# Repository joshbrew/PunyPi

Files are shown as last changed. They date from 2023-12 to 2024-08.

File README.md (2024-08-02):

# PunyPi (tbd)

rn_image_picker_lib_temp_c4f592c4-a881-4eb2-ad05-ee595f95a4bf

This is a standalone chiplet design that mounts the [TI AM625](https://www.ti.com/product/AM625) CortexA53 (up to 4 cores) and up to 8Gb DDR4 RAM. This chiplet allows you to create expansion boards in any size and shape you desire, and it's fully open source! This variant of the A53 runs at a higher clock than the RPi Zero 2 and we included the RAM so it is fully capable of more intensive compute tasks. 

This doesn't break out *every* feature of the AM625 but it does condense a fair amount to 30mm x 30mm on a 10 layer board. It works with standard throughole vias to help reduce PCB assembly costs. The Cortex A53 is getting older but is still one of the most popular industrial automation chips in the world and gives you good middle of the road performance - about that of a Samsung Galaxy S8 (EU edition) or Galaxy Watch 3. We're experimenting with microcomputers, servers, wearables, etc. and our best option was to design this base chiplet ourselves. 

Features:
- 1x DDR4 up to 8Gb
- 2x USB 2.0
- 1x LVDS screen (can bridge to HDMI) up to 1080p 60fps with up to Vulkan 1.2 support
- 1x JTAG
- 1x McASP Audio (4 channel)
- 2x RGMII Ethernet
- 1x MMC 5.1
- 1x SD 3.0
- UART, SPI, I2C, GPIO (and unused interfaces generally work as GPIO)
- Can be powered by 3.3V supply (up to 4A) which may change.

## Currently untested! Stay tuned!

Files were produced in Altium. You can import the PcbDoc to KiCAD there is an ASCII exported version for EAGLE importing. Chiplet footprints forthcoming for easily creating mounts for the chiplet.

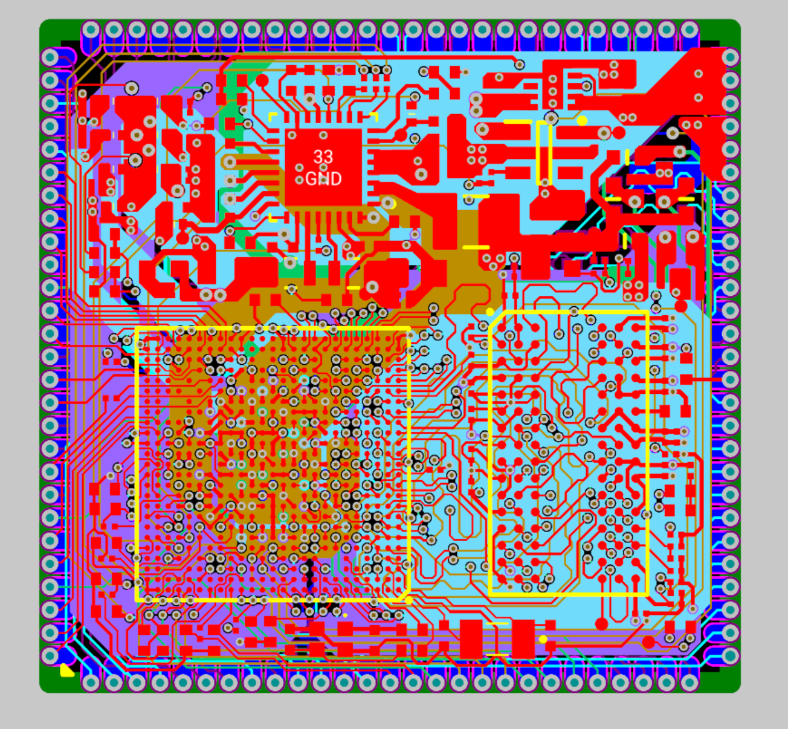
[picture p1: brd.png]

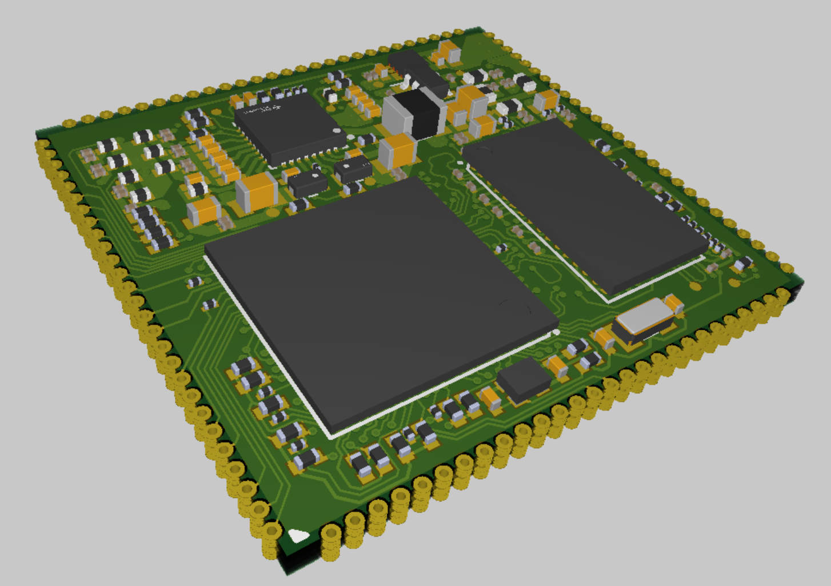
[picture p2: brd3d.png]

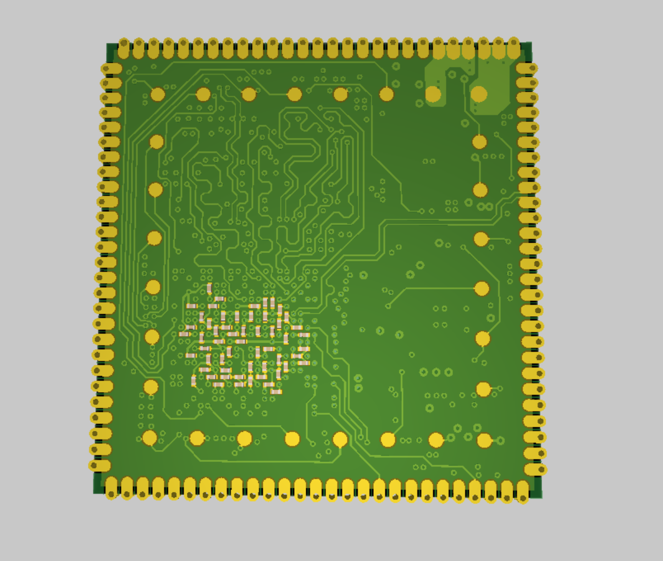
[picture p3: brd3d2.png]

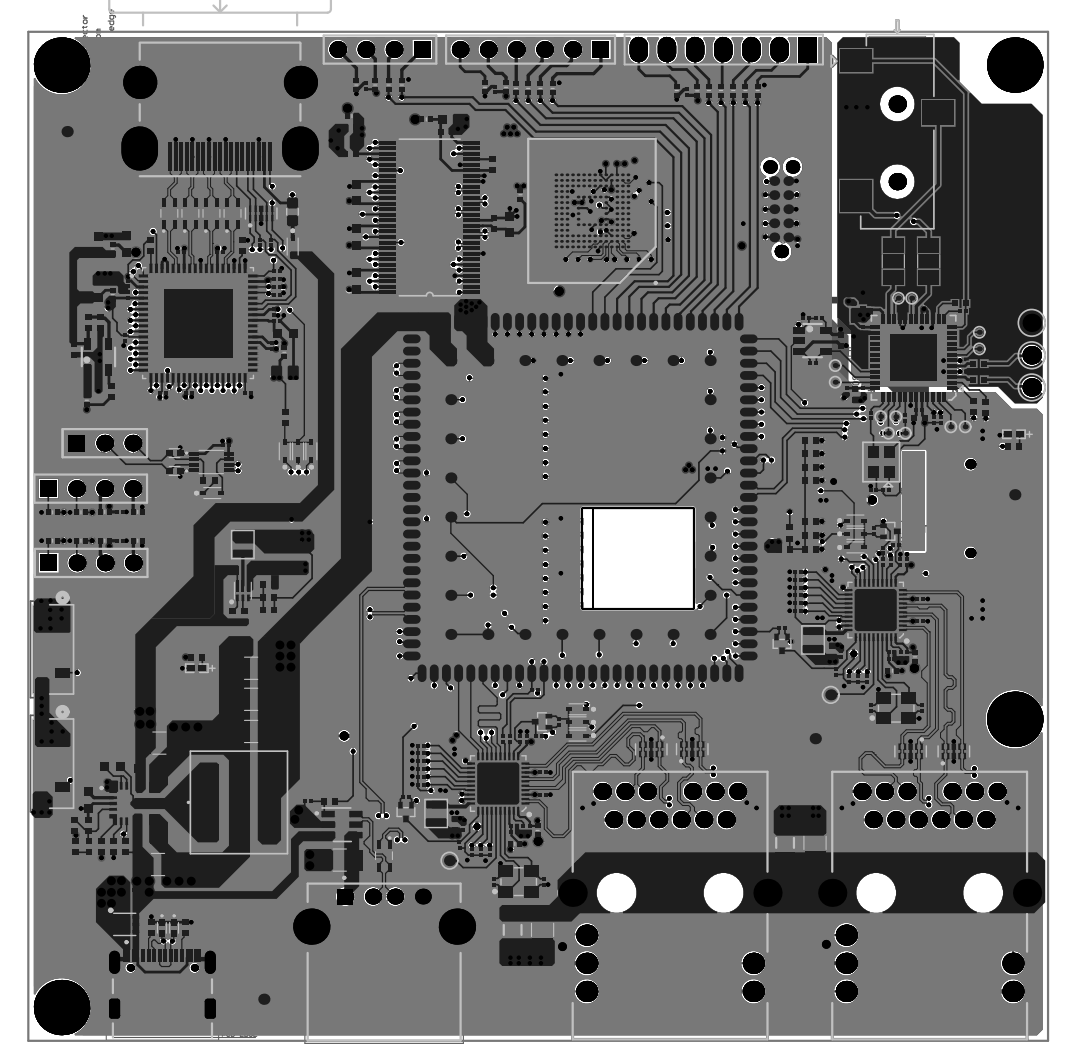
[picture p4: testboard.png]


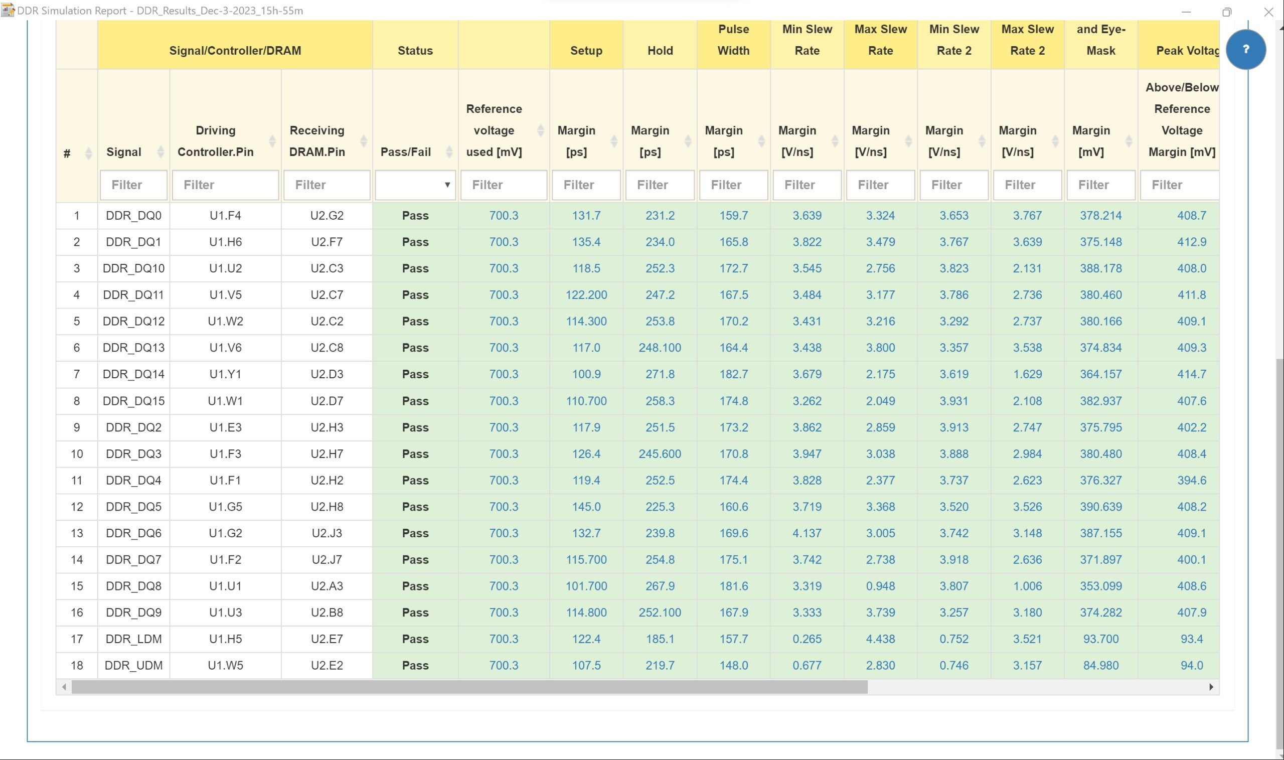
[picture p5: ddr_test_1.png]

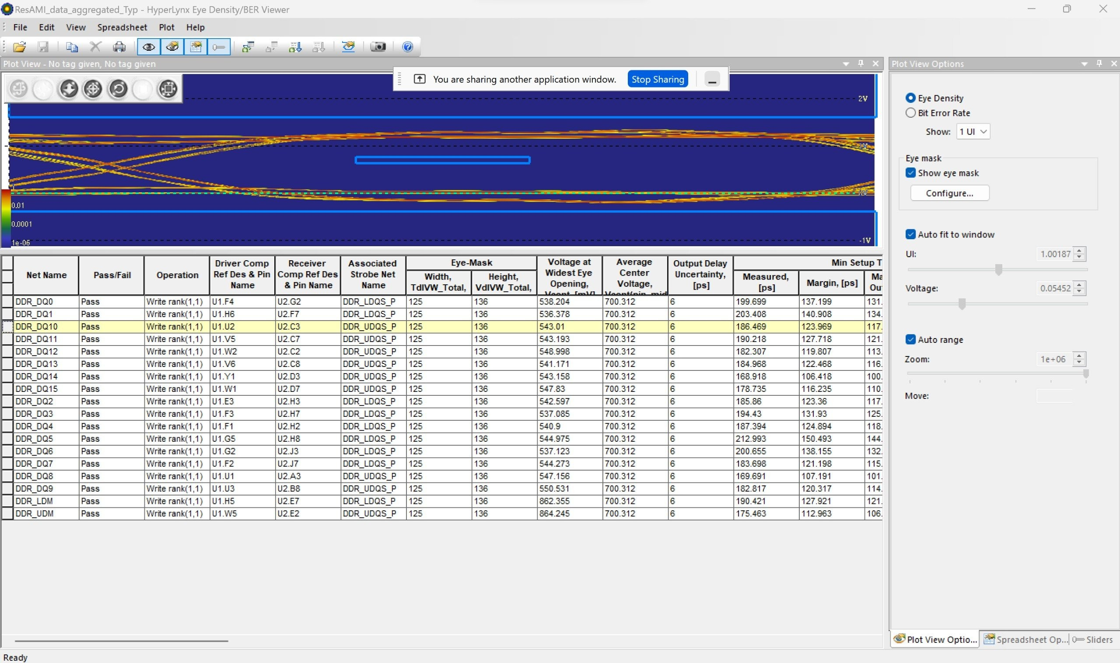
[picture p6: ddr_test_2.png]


We will release attachment/expansion boards for this that come prefabbed with ports etc, while the base board is just a chiplet. TI comes with standard toolings for flashing these devices, no licenses or anything required. We'll have all of this process documented for you on a full release. 

## License:

Drawings licensed under GNU GPL v3.0 (copyleft)

Please contribute to a future that's open source!

Credits:

- Drawing and validation by Nham (Paul) Phan
- Ideas/specifications by Josh Brewster and Yassine Santissi 

## Why

This is a FULLY open source alternative to RPi Zero 2. Just pay it forward and contribute to FOSS and open hardware. We're working on getting a bulk order to make these devices available at competitive prices with standard expansion boards built to house our modular ARM + RAM chiplet. We were inspired by Arducam's similar attempt with an older chipset that never saw the light of day.

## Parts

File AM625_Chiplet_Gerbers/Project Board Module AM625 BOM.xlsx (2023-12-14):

 |  | Bom List Som AM625
STT | Part Number | Manufacturer | Description | Designator | Footprint | Quantity
1 | C0603X5R1C103K030BA | TDK Corporation | CAP CER .01UF 16V 10% X5R 0201 | C1, C5, C6, C7, C8, C11, C12, C13, C14, C15, C16, C17, C18, C59, C62, C66, C69, C72, C75, C78, C81, C84, C135 | C0201 | 23
2 | C0603X5R1C104K030BC | TDK Corporation | CAP CER 0.1UF 16V 10% X5R 0201 | C2, C3, C10, C19, C20, C21, C58, C61, C65, C68, C71, C74, C77, C80, C83, C86, C91, C92, C93, C94, C95, C96, C97, C98, C99, C100, C101, C102, C103, C106, C107, C108, C109, C110, C111, C112, C113, C116, C117, C118, C119, C123, C124, C125, C126, C129, C130, C131, C132, C133, C134 | C0201 | 51
3 | C1005X5R1A225K | TDK Corporation | CAP CER 2.2UF 10V 10% X5R 0402 | C4, C29, C30, C32, C33, C35, C36, C37, C38 | C0402 | 9
4 | C1608X5R1A226M080AC | TDK Corporation | CAP CER 22UF 10V X5R 0603 | C9 | C0603 | 1
5 | CL21A476MQYNNNG | Samsung | 47 µF ±20% 6.3V Ceramic Capacitor X5R 0805 (2012 Metric) | C22, C28, C31 | C0805 | 3
6 | CL10A106MQ8NNNC | Samsung | 10 µF ±20% 6.3V Ceramic Capacitor X5R 0603 (1608 Metric) | C23, C40, C88, C120 | C0603 | 4
7 | C1005X5R1A475M | TDK Corporation | CAP CER 4.7UF 10V 20% X5R 0402 | C24, C25, C26, C27, C34 | C0402 | 5
8 | CL03A105KQ3CSNC | Samsung | CAP CER 1UF 6.3V X5R 0201 | C39, C42, C64, C67, C73, C79, C82, C87 | C0201 | 8
9 | C1005X5R1C105K | TDK Corporation | CAP CER 1.0UF 16V X5R 0402 | C41 | C0402 | 1
10 | C1005X5R1H104K | TDK Corporation | CAP CER .10UF 50V X5R 10% 0402 | C43 | C0402 | 1
11 | GJM1555C1H180JB01D | Murata | CAP CER 18PF 50V C0G/NP0 0402 | C44, C45 | C0402 | 2
12 | GJM1555C1H9R0DB01D | Murata | CAP CER 9PF 50V C0G/NP0 0402 | C46, C47 | C0402 | 2
13 | CL03A105KQ3CSNC | Samsung | CAP CER 1UF 6.3V X5R 0201 | C48, C49, C50, C51, C52, C53, C54, C55, C56, C90, C105, C115, C122, C128 | C0201 | 14
14 | C0603C0G1H2R2C030BA | TDK Corporation | CAP CER 2.2PF 50V C0G 0201 | C57 | C0201 | 1
15 | GRM035R60J475ME15D | Murata | CAP CER 4.7UF 6.3V X5R 0201 | C60, C63, C70, C76, C85, C89, C104, C114, C121, C127 | C0201 | 10
16 | BLM15PX121SN1D | Murata | FERRITE BEAD 120 OHM 0402 1LN | FL1, FL2, FL4, FL5, FL6, FL8, FL10, FL12, FL13 | NFZ15SG152SN10B | 9
17 | BLM18SG260TN1D | Murata | FERRITE BEAD 26 OHM 0603 1LN | FL3, FL7, FL9, FL11 | BLM18EG101TH1D | 4
18 | TPS6521904RHBR | Texas Instruments | INTEGRATED POWER MANAGEMENT | IC1 | 32-VQFN (5x5) | 1
19 | TPS22965DSGT | Texas Instruments | Integrated Circuit | IC2 | SON50P200X200X80-9N | 1
20 | TLV75518PDBVR | Texas Instruments | IC REG LINEAR 1.8V 500MA SOT23-5 | IC3 | SOT95P280X145-5N | 1
21 | DFE322520F-R47M=P2 | Murata | FIXED IND 0.47UH 8.5A | L1 | INDC3225X20N | 1
22 | TFM201208BLE-R47MTCF | TDK | 470 nH Shielded Thin Film Inductor 4 A 29mOhm Max 0805 (2012 Metric) | L2, L3 | FP-TFM201208BLE-R47MTCF_0805-MFG | 2
23 | RC0201FR-071KL | Yageo | RES 1K OHM 1/20W 1% 0201 SMD | R1, R2, R6, R7, R9, R12 | R0201 | 6
24 | RMCF0402FT39R2 | Stackpole Electronics | RES 39.2 OHM 1% 1/16W 0402 | R3, R4 | R0402 | 2
25 | RMCF0201FT240R | Stackpole Electronics Inc | RES 240 OHM 1/20W 1% 0201 | R5 | R0201 | 1
26 | RMCF0402FT240R | Stackpole Electronics Inc | RES TF 240 OHM 1% 0.0625W 0402 | R8 | R0402 | 1
27 | RC0201FR-0710KL | Yageo | RES 10K OHM 1/20W 1% 0201 SMD | R10, R11, R17, R32, R40, R41 | R0201 | 6
28 | RC0402FR-0722RL | Yageo | RES 22.0 OHM 1/16W 1% 0402 SMD | R13, R16 | R0402 | 2
29 | RC0402JR-070RL | Yageo | RES 0.0 OHM 1/16W 0402 SMD | R14, R26, R27, R28, R38, R39, R42 | R0402 | 7
30 | RC0402FR-0749R9L | Yageo | RES 49.9 OHM 1/16W 1% 0402 SMD | R15 | R0402 | 1
31 | RC0402FR-0710KL | Yageo | RES 10.0K OHM 1/16W 1% 0402 SMD | R18, R19, R20, R21, R29, R30, R53, R55, R57, R58 | R0402 | 10
32 | RC0201JR-070RL | Yageo | RES 0 OHM JUMPER 1/20W 0201 | R22, R23, R24, R25, R31 | R0201 | 5
33 | RC0402FR-072K2L | Yageo | RES 2.20K OHM 1/16W 1% 0402 SMD | R33, R34, R36, R37, R43, R44, R45, R46 | R0402 | 8
34 | RC0201FR-0733RL | Yageo | RES 33 OHM 1% 1/20W 0201 | R35, R47, R48, R51, R52 | R0201 | 5
35 | RC0201FR-0756K2L | Yageo | RES 56.2K OHM 1% 1/20W 0201 | R49 | R0201 | 1
36 | RC0201FR-079K76L | Yageo | RES 9.76K OHM 1% 1/20W 0201 | R50 | R0201 | 1
37 | RT0402BRD07499RL | Yageo | RES SMD 499 OHM 0.1% 1/16W 0402 | R54, R56 | R0402 | 2
38 | AM6254ATCGHAALW | Texas Instruments | ARM® Cortex®-A53 Microprocessor IC Sitara™ 4 Core, 64-Bit 1.4GHz 425-FCCSP (13x13) | U1 | BGA425C50P25X25_1300X1300X89 | 1
39 | MT40A1G16TB-062E:F | Micron Technology | SDRAM - DDR4 Memory IC 16Gbit Parallel 1.5 GHz 96-FBGA (7.5x13) | U2 | BGA96C80P9X16_750X1300X120 | 1
40 | XRCGB25M000F3M00R0 | Murata | CRYSTAL 25.0000MHZ 6PF SMD | Y1 | XRCGB25M000F3M00R0 | 1
41 | ECS-.327-9-34QCS-TR | ECS International | CRYSTAL 32.7680KHZ 9PF SMD | Y2 | ECS327934QSTR | 1

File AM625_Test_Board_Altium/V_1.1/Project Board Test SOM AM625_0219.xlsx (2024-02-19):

Manufacturer Part Number | Description | Manufacturer | Comment | Designator | Footprint | LibRef | Quantity
CGA3E1X5R1C105K080AC | Multilayer Ceramic Capacitor, 1 uF, 16 V, ± 10%, X5R, 0603 [1608 Metric] | TDK | 1uF | C101, C103, C105 | C0603 | CGA3E1X5R1C105K080AC | 3
C3216X5R1C106K160AA | Multilayer Ceramic Capacitor, 10 uF, 16 V, ± 10%, X5R, 1206 [3216 Metric] | TDK | 10uF | C102, C104 | C1206B/3216MM | C3216X5R1C106K160AA | 2
C3216X5R1C476M160AB, GRM31CR61A476ME15L | Multilayer Ceramic Capacitor, 47 uF, 16 V, ± 20%, X5R, 1206 [3216 Metric], Multilayer Ceramic Capacitor, 47 uF, 10 V, ± 20%, X5R, 1206 [3216 Metric] | TDK, Murata | 47uF | C106, C107, C108, C815, C816 | C1206B/3216MM | C3216X5R1C476M160AB, GRM31CR61A476ME15L | 5
C1608X7R1E104K080AA | Multilayer Ceramic Capacitor, 0.1 uF, 25 V, ± 10%, X7R, 0603 [1608 Metric] | TDK | 100nF | C109, C110, C302, C303, C304, C305, C307, C309 | C0603 | C1608X7R1E104K080AA | 8
CC0402FRNPO9BN360 | Capacitor Ceramic 36pF 50V C0G 1% 0402 Paper T/R | Yageo | 36pF | C111 | C0402 | CC0402FRNPO9BN360 | 1
C1608X5R1A106K080AC | Multilayer Ceramic Capacitor, 10 uF, 10 V, ± 10%, X5R, 0603 [1608 Metric] | TDK | 10uF | C112, C311, C318, C319, C322, C323, C701, C703 | C0603 | C1608X5R1A106K080AC | 8
C0402C121J3GAC7867 | Cap Ceramic 120pF 25V C0G 5% SMD 0402 125°C Paper T/R | KEMET | 120pF | C113 | C0402 | C0402C121J3GAC7867 | 1
CC0805MKX5R8BB226 | 22 µF ±20% 25V Ceramic Capacitor X5R 0805 (2012 Metric) | Yageo | 22uF | C114, C115, C213, C214 | C0805 | CC0805MKX5R8BB226 | 4
CC0402KRX5R6BB105 | Multilayer Ceramic Capacitor, 1 uF, 16 V, ± 20%, C0G (NP0), 0201 [0603 Metric] | Yageo | 1uF | C116, C117 | C0402 | CC0402KRX5R6BB105 | 2
CC0201KRX5R6BB104 | Multilayer Ceramic Capacitor, 0.1 uF, 16 V, ± 10%, X5R, 0201 [0603 Metric] | Yageo | 100nF | C201, C202, C203, C204, C206, C207, C208, C209, C210, C212, C216, C217, C312, C313, C314, C315, C316, C317, C320, C321, C324, C325, C326, C327, C502, C504, C506, C508, C510, C511, C512, C513, C515, C602, C604, C606, C608, C610, C611, C612, C613, C615, C702, C705, C901, C902, C903, C904, C905, C906, C907 | C0201 | CC0201KRX5R6BB104 | 51
CC0402MRX5R5BB475 | Multilayer Ceramic Capacitor, 4.7 uF, 6.3V, ± 10%, X5R, 0402 [1005 Metric] | Yageo | 4.7uF | C205, C211, C215, C301, C501, C505, C514, C601, C605, C614 | C0402 | CC0402MRX5R5BB475 | 10
C0402C103K4REC7411 | ESD SMD Comm X7R 0402 (1005Metric) ceramic capacitor 0.039Lx0.020W 1.00mmx0.50mm X7R ±10% 10000pF | KEMET | 10nF | C306, C308, C310 | C0402 | C0402C103K4REC7411 | 3
CC0201MRX5R5BB105 | 1 µF ±20% 6.3V Ceramic Capacitor X5R 0201 (0603 Metric) | Yageo | 1uF | C503, C507, C509, C603, C607, C609 | C0201 | CC0201MRX5R5BB105 | 6
C1005X5R1H104K050BB | Multilayer Ceramic Capacitor, 0.1 uF, 50 V, ± 10%, X5R, 0402 [1005 Metric] | TDK | 100nF | C516, C517, C518, C519, C520, C616, C617, C618, C619, C620 | C0402 | C1005X5R1H104K050BB | 10
CC0201JRNPO9BN220 | 0201 22 pF 50 V ±5 % Tolerance NP0 SMT Multilayer Ceramic Capacitor | Yageo | 22pF | C521, C522, C621, C622 | C0201 | CC0201JRNPO9BN220 | 4
C1206C102KDRACAUTO | Cap Ceramic 0.001uF 1000V X7R 10% Pad SMD 1206 125°C Low ESR Automotive Medical T/R | KEMET | 1nF | C523, C623 | C1206B/3216MM | C1206C102KDRACAUTO | 2
C3216X5R1A107M160AC | Multilayer Ceramic Capacitor, C Series, 100 - F, - 20%, X5R, 10 V, 1206 [3216 Metric] | TDK | 100uF | C704 | C1206B/3216MM | C3216X5R1A107M160AC | 1
GRM155R61A106ME11D | Multilayer Ceramic Capacitor, 10 uF, 10 V, ± 20%, X5R, 0402 [1005 Metric] | Murata | 10uF | C801, C803, C805, C806, C809 | C0402 | GRM155R61A106ME11D | 5
GRM033R61C104KE14D | Multilayer Ceramic Capacitor, 0.1 uF, 16 V, ± 10%, X5R, 0201 [0603 Metric] | Murata | 0.1uF | C802, C804, C807, C808, C810, C813, C814, C818 | C0201 | GRM033R61C104KE14D | 8
GRM155R71H104KE14D | Multilayer Ceramic Capacitor, 0.1 uF, 50 V, ± 10%, X7R, 0402 [1005 Metric] | Murata | 0.1uF | C811, C812, C819 | C0402 | GRM155R71H104KE14D | 3
GRM155R71A474KE01D | Multilayer Ceramic Capacitor, 0.47 uF, 10 V, ± 10%, X7R, 0402 [1005 Metric] | Murata | 0.47uF | C817 | C0402 | GRM155R71A474KE01D | 1
RB520S30T1G | Diode Schottky 30V 0.2A 2-Pin SOD-523 T/R - Product that comes on tape, but is not reeled | ON Semiconductor | RB520S30T1G | D201, D202, D203, D204, D205, D301, D303, D304, D305, D503, D504, D505, D603, D604, D605, D905 | sod_523 | RB520S30T1G | 16
TPD1E1B04DPYR | 1-pF, ±3.6-V, ±30-kV ESD protection diode with 6-A 8/20-uS surge & Low Clamping in 0402 package | Texas Instruments | TPD1E1B04DPYR | D206, D207, D208, D209, D210, D211, D212, D701, D702, D901, D902, D903, D904, D906, D907, D908, D909, D910, D911, D912, D913, D914, D915, D916, D917, D918 | DIO_TPD1E05U06DPYR | TPD1E1B04DPYR | 26
TPD4E05U06DQAR | Quad 0.5-pF, 5.5-V, ±12-kV ESD protection diode for USB, HDMI & High Speed Interfaces | Texas Instruments | TPD4E05U06DQAR | D302, D501, D502, D601, D602 | 10-USON | TPD4E05U06DQAR | 5
MF-FSMF010X-2 | PTC Resettable Fuse 0.1A(hold) 0.3A(trip) 15V 40A 0.5W 1s 0.9Ohm SMD Solder Pad 0603 T/R Automotive | Bourns | MF-FSMF010X-2 | F301 | f0603 | MF-FSMF010X-2 | 1
BLM15PD121SZ1D | Ferrite Beads Multi-Layer 120Ohm 25% 100MHz 1.3A 0.09Ohm DCR 0402 Automotive T/R | Murata | 120R | FB101, FB301, FB302, FB303, FB304, FB305, FB306, FB501, FB502, FB503, FB504, FB601, FB602, FB603, FB604, FB801, FB901, FB902, FB903, FB904, FB905, FB906, FB907, FB908, FB909, FB910, FB911, FB912, FB913, FB914, FB915, FB916, FB917, FB918, FB919, FB920, FB921, FB922, FB923, FB924, FB925 | FB0402 | BLM15PD121SZ1D | 41
GTFP08432B1HR | MICRO SD PUSH/PUSH SMALL 8C | Amphenol | GTFP08432B1HR | J201 | AMPHENOL_GTFP08432B1HR | CONN; MICRO SD PUSH/PUSH SMALL 8C, 5033981892 | 1
47151-0001 | CONN RCPT 19POS HDMI RT ANG SMD | Molex Connector Corporation | 47151-0001 | J301 | HDMI | 47151-0001 | 1
L829-1J1T-43 | CONN MAGJACK 1PORT SHLD 1000BT | Bel Fuse Inc | L829-1J1T-43 | J501, J601 | L829-1J1T-43 | L829-1J1T-43 | 2
USB4105-GF-A | Conn USB 2.0 Type C RCP 24 POS 0.3mm/0.5mm Solder RA SMD 24 Terminal 1 Port T/R | Global Connector Technology | TYPE_C 2.0 | J701 | GCT_USB4105-GF-A | USB4105-GF-A | 1
USB1130-15-A | Usb Conn, 2.0 Type A, R/a Rcpt, 4Pos, Th Rohs Compliant: Yes | Global Connector Technology | USB_A | J702 | GCT_USB1130-15-A_REVA | USB1130-15-A | 1
SJ-43514-SMT-TR | 3.5 mm, 4 Conductors, Right Angle, Surface Mount (SMT), Audio Jack Connector | CUI Devices | SJ-43514-SMT-TR | J801 | CON_AV4_SJ-43514-SMT_S_R_S_5-1 | SJ-43514-SMT-TR | 1
TS-104-T-AA | Header, 4 Pin Pitch 2.54mm |  | Header 4P | J901, J903, J905 | HDR1X4 | Header 4x1 | 3
TS-103-T-A |  |  | Header 1x3 | J904 | HDR1X3 | Header 1x3 | 1
74439358047 | Fixed Ind 4.7UH 9.5A 8.65 Mohm | Wurth Electronics | 4.7uH | L101 | IND_WE-XHMI_8080_WRE | 74439358047 | 1
DFE201610E-R47M=P2 | Inductor Power Shielded Wirewound 0.47uH 20% 1MHz Metal 3.6A 0.032Ohm DCR 0806 T/R | Murata | 0.47uH | L102 | l2016 | DFE201610E-R47M=P2 | 1
DLW21SN900HQ2L | Ind Common Mode Choke Wirewound 90Ohm 25% 100MHz 280mA 0805 Embossed T/R | Murata | DLW21SN900HQ2L | L301, L302, L303, L304, L701, L702 | IND_DLW21S_0805_MUR | DLW21SN900HQ2L | 6
DFE201610P-2R2M=P2 | Inductor Power Shielded Wirewound 2.2uH 20% 1MHz Metal 1.4A 0.168Ohm DCR 0806 T/R | Murata | 2.2uH | L501, L601 | l2016 | DFE201610P-2R2M=P2 | 2
BL-HGE37A-AV-TRB | Yellow Green 0402 1X.5X4MM | American Bright | Green | LED1001 | led0402_G | BL-HGE37A-AV-TRB | 1
SML-P12U2TT86R | LED Uni-Color Red 2-Pin Chip 0402(1006Metric) T/R | Rohm | Red | LED1002 | led0402_R | SML-P12U2TT86R | 1
TS-107-T-A | Header, 7-Pin, 2.54mm |  | Header 7 | P901 | HDR1X7 | Header 7x1 | 1
TS-106-T-A | Header, 6-Pin |  | Header 6 | P902 | HDR1X6 | Header 6x1 | 1
DMG1012T-7 | Transistor MOSFET NTR4003NT1G, SOT23, ON Semi | Diodes | DMG1012T-7 | Q501, Q502, Q601, Q602 | sot_523 | DMG1012T-7 | 4
RC0402FR-07100KL, AC0402FR-07100KL | SMD Chip Resistor, 100 kOhm, ± 1%, 63 mW, 0402 [1005 Metric], Thick Film, General Purpose | Yageo | 100K | R101, R103, R104, R110, R113 | R0402 | RC0402FR-07100KL, AC0402FR-07100KL | 5
RC0402FR-071KL | SMD Chip Resistor, 1 kOhm, ± 1%, 63 mW, 0402 [1005 Metric], Thick Film, General Purpose | Yageo | 1K | R102, R507, R508, R607, R608, R703 | R0402 | RC0402FR-071KL | 6
RC0402FR-0732K4L | SMD Chip Resistor, 32.4 kOhm, ± 1%, 63 mW, 0402 [1005 Metric], Thick Film, General Purpose | Yageo | 32.4K | R105 | R0402 | RC0402FR-0732K4L | 1
RC0402FR-0743K2L | SMD Chip Resistor, 43.2 kOhm, ± 1%, 63 mW, 0402 [1005 Metric], Thick Film, General Purpose | Yageo | 43.2K | R106 | R0402 | RC0402FR-0743K2L | 1
RC0402FR-0710KL | RES 10.0K OHM 1/16W 1% 0402 SMD | Yageo | 10K | R107, R108, R111, R210, R213, R214, R217, R218, R219, R220, R222, R223, R315, R901, R902, R903, R904, R905, R906, R907 | R0402 | RC0402FR-0710KL | 20
RC0402FR-07200KL | SMD Chip Resistor, 200 kOhm, ± 1%, 63 mW, 0402 [1005 Metric], Thick Film, General Purpose | Yageo | 200K | R109 | R0402 | RC0402FR-07200KL | 1
RC0402FR-07118KL | SMD Chip Resistor, 118 kOhm, ± 1%, 63 mW, 0402 [1005 Metric], Thick Film, General Purpose | Yageo | 118K | R112 | R0402 | RC0402FR-07118KL | 1
RC0402FR-0749K9L | SMD Chip Resistor, 49.9 kOhm, ± 1%, 63 mW, 0402 [1005 Metric], Thick Film, General Purpose | Yageo | 49.9K | R201, R202, R203, R204, R205, R206, R207, R208, R209, R212 | R0402 | RC0402FR-0749K9L | 10
RC0402JR-070RL | Zero Ohm Resistor, Jumper, 0402 [1005 Metric], Thick Film, 63 mW, 1 A, Surface Mount | Yageo | 0R | R211, R215, R216, R805, R806 | R0402 | RC0402JR-070RL | 5
RC0402FR-0710KL | RES 10.0K OHM 1/16W 1% 0402 SMD | Yageo | NC | R221 | R0402 | RC0402FR-0710KL | 1
RC0402FR-07100RL | SMD Chip Resistor, 100 Ohm, ± 1%, 63 mW, 0402 [1005 Metric], Thick Film, General Purpose | Yageo | 100R | R301, R304, R305, R306, R307 | R0402 | RC0402FR-07100RL | 5
RC0402JR-072K4L | Res Thick Film 0402 2.4K Ohm 5% 1/16W ±100ppm/°C Molded SMD Paper T/R | Yageo | 2.4K | R302, R303 | R0402 | RC0402JR-072K4L | 2
RC0201FR-072K2L | SMD Chip Resistor, 2.2 kOhm, ± 1%, 50 mW, 0201 [0603 Metric], Thick Film, General Purpose | Yageo | 2.2K | R308, R309, R502, R602, R803 | R0201 | RC0201FR-072K2L | 5
RC0402FR-074K7L | SMD Chip Resistor, 4.7 kOhm, ± 1%, 63 mW, 0402 [1005 Metric], Thick Film, General Purpose | Yageo | 4.7K | R310 | R0402 | RC0402FR-074K7L | 1
RC0201JR-0710KL, RC0201FR-0710KL | Res Thick Film 0201 10K Ohm 5% 1/20W ±200ppm/°C Molded SMD SMD Paper T/R, SMD Chip Resistor, 10 kOhm, ± 1%, 50 mW, 0201 [0603 Metric], Thick Film, General Purpose | Yageo | 10K | R311, R312, R520, R521, R524, R525, R620, R621, R624, R625, R807, R809, R810, R811, R814 | R0201 | RC0201JR-0710KL, RC0201FR-0710KL | 15
RC0402FR-074K3L | SMD Chip Resistor, 4.3 kOhm, ± 1%, 63 mW, 0402 [1005 Metric], Thick Film, General Purpose | Yageo | 4.3K | R313 | R0402 | RC0402FR-074K3L | 1
RC0201JR-070RL | Zero Ohm Resistor, Jumper, 0201 [0603 Metric], Thick Film, 50 mW, 500 mA, Surface Mount | Yageo | 0R | R314, R503, R504, R603, R604, R801, R802, R804, R808 | R0201 | RC0201JR-070RL | 9
RC0201FR-071K1L | SMD Chip Resistor, 1.1 kOhm, ± 1%, 50 mW, 0201 [0603 Metric], Thick Film, General Purpose | Yageo | 1.1K | R401, R402, R403, R404, R405, R406, R407, R408, R409, R410, R411, R412, R413, R414, R415, R416 | R0201 | RC0201FR-071K1L | 16
RC0201FR-07100KL | SMD Chip Resistor, 100 kOhm, ± 1%, 50 mW, 0201 [0603 Metric], Thick Film, General Purpose | Yageo | 100K | R417, R418, R419, R420, R421, R422, R423, R424, R425, R426, R427, R428, R429, R430, R431, R432 | R0201 | RC0201FR-07100KL | 16
RC0402JR-070RL | Zero Ohm Resistor, Jumper, 0402 [1005 Metric], Thick Film, 63 mW, 1 A, Surface Mount | Yageo | DNP | R501, R506, R601, R606 | R0402 | RC0402JR-070RL | 4
RC0201FR-072K49L | SMD Chip Resistor, 2.49 kOhm, ± 1%, 50 mW, 0201 [0603 Metric], Thick Film, General Purpose | Yageo | 2.49K | R505, R605 | R0201 | RC0201FR-072K49L | 2
RC1206FR-071ML | SMD Chip Resistor, 1 MOhm, ± 1%, 250 mW, 1206 [3216 Metric], Thick Film, General Purpose | Yageo | 1M | R509, R609 | R1206B/3216MM | RC1206FR-071ML | 2
RC0201JR-074K7L | SMD Chip Resistor, 4.7 kOhm, ± 5%, 50 mW, 0201 [0603 Metric], Thick Film, General Purpose | Yageo | 4.7K | R510, R512, R515, R516, R518, R522, R526, R528, R531, R610, R612, R615, R616, R618, R622, R626, R628, R631 | R0201 | RC0201JR-074K7L | 18
RC0201JR-074K7L | SMD Chip Resistor, 4.7 kOhm, ± 5%, 50 mW, 0201 [0603 Metric], Thick Film, General Purpose | Yageo | DNP | R511, R513, R514, R517, R519, R523, R527, R529, R530, R611, R613, R614, R617, R619, R623, R627, R629, R630 | R0201 | RC0201JR-074K7L | 18
AC0402FR-075K1L | SMD Chip Resistor, 5.1 kOhm, ± 1%, 63 mW, 0402 [1005 Metric], Thick Film, General Purpose | Yageo | 5.1K | R701, R702 | R0402 | AC0402FR-075K1L | 2
RC0201JR-0710KL | Res Thick Film 0201 10K Ohm 5% 1/20W ±200ppm/°C Molded SMD SMD Paper T/R | Yageo | DNI | R812, R813, R815 | R0201 | RC0201JR-0710KL | 3
RC0402FR-072K2L | SMD Chip Resistor, 2.2 kOhm, ± 1%, 63 mW, 0402 [1005 Metric], Thick Film, General Purpose | Yageo | 2.2K | R1001, R1002 | R0402 | RC0402FR-072K2L | 2
416131160808 | Slide Dip Switch, 8 Switches, 8PST, Latched, 0.025A, 24VDC, Solder Terminal, Surface Mount-straight | Wurth Electronics | 416131160808 | SW401, SW402 | SW_416131160808 | 416131160808 | 2
TL3330AF260QG | Switch Tactile N.O. SPST Rectangular Button Gull Wing 0.05A 12VDC 2.55N SMD | E-Switch | TL3330AF260QG | SW1001, SW1002 | SW_TL3330_EWI | TL3330AF260QG | 2
LMQ61460AASRJRR | Industrial 3-V to 36-V, 6-A, low-noise synchronous step-down converter 14-VQFN-HR -40 to 150 | Texas Instruments | LMQ61460AASRJRR | U101 | 14-VFQFN | LMQ61460AASRJRR | 1
TLV62595DMQR | 2.5-V to 5.5-V input, 4-A step-down converter with 1% output accuracy in 1.5-mm x 1.5-mm QFN package 6-VSON-HR -40 to... | Texas Instruments | TLV62595DMQR | U102 | VSON6_0D5_1D5X1D5X1MM | TLV62595DMQR | 1
TLV75801PDBVR | Adjustable 500-mA low-dropout (LDO) regulator 5-SOT-23 -40 to 125 | Texas Instruments | TLV75801PDBVR | U103 | SOT23-5 | TLV75801PDBVR | 1
KLMBG2JETD-B041 | eMMC 5.1 BGA-153 eMMC ROHS |  | KLMBG2JETD-B041 | U201 | BGA153C50P14X14_1150X1300X80 | KLMAG1JETD-B041 | 1
TPS22918DBVR | IC SINGLE CHANNEL LOAD SWITCH | Texas Instruments | TPS22918DBVR | U202 | SOT23-6 | TPS22918DBVR | 1
SN75LVDS82DGGR | 0/5 Receiver LVDS 56-TSSOP | Texas Instruments | SN75LVDS82DGGR | U301 | SOP50P810X120-56N | SN75LVDS82DGGR | 1
SII9022ACNU | 24-Bit RGB Input HDMI 1.4a Transmitter, 1080p@60Hz, no HDCP, 72-pin QFN | Lattice Semiconductor | SII9022ACNU | U302 | QFN50P1000X1000X90-73N | SII9022ACNU | 1
RTL8211F-VD-CG | IC, Interface, Ethernet, RTL8211F-VD-CG, QFN-40(5*5) | Realtek | RTL8211 | U501, U601 | qfn40_0D4_5x5mm | RTL8211 | 2
TVS0500DRVR | Diode TVS Single Uni-Dir 5V 400W 6-Pin WSON EP T/R | Texas Instruments | TVS0500DRVR | U701 | wson6_0d65_2x2x0_8mm | TVS0500DRVR | 1
TPD3S014DBVR | Current-limit switch and D+/D– ESD protection for USB Host ports 6-SOT-23 -40 to 85 | Texas Instruments | TPD3S014DBVR | U702 | SOT23-6 | TPD3S014DBVR | 1
TLV320AIC3106IRGZT | Very-Low-Power Stereo Audio CODEC With PowerTune Technology 32-VQFN -40 to 85 | Texas Instruments | TLV320AIC3106IRGZT | U801 | VQFN48_19-68_285X285 | TLV320AIC3204IRHBR | 1
KC2520Z12.2880C1KX00 | 12.288 MHz XO (Standard) CMOS Oscillator 1.71V ~ 3.63V Standby (Power Down) 4-SMD, No Lead | Kyocera AVX | 12.288MHz | U802 | OSC4_KC2520B_100X80_SMD_0-8 | XTAL OSC XO 12.2880MHZ CMOS SMD | 1
SN74LVC1G08DBVRE4 | Single 2-input, 1.65-V to 5.5-V AND gate 5-SOT-23 -40 to 125 | Texas Instruments | SN74LVC1G08DBVRE4 | U803 | SOT23-5 | SN74LVC1G08DBVRE4 | 1
SN74LVC2G241DCUR | Buffer, Non-Inverting 2 Element 1 Bit per Element Push-Pull Output US8 | Texas Instruments | SN74LVC2G241DCUR | U901 | DCU8-M | SN74LVC2G241DCUR | 1
LFXTAL055299 | Crystal, 25MHZ, 18PF, SMD | IQD | 25MHz | Y501, Y601 | x4-smd-3_2x2_5x1_0mm | LFXTAL055299 | 2
TC2050-IDC | PLUG-OF-NAILS 10-PIN W/ LEGS 8" | Tag-Connect LLC | TC2050-IDC | J902 | Header 2x5 |  | 1

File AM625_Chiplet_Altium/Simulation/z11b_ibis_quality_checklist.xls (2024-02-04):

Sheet: summary
This checklist will help validate the quality of an IBIS file.
Copy the component and Model tabs below so that this spreadsheet contains one tab
for each [Component] and [Model]. Fill in the tabs to determine the quality level for
each item, then complete the summary of IQ levels below to determine the overall
IQ level. For more information check the IBIS Quality Specification
Vendor | Micron Technology, Inc.
IBIS File | z11b.ibs
IBIS File | z11b_it.ibs
Rev | 2.9.2
Date | 2023-02-27
Overall IBIS Quality | 3MSX
IBISCHK Parser Information
Version | 6.1.2
Errors | 0
Warnings | 0
Caution | 0
Notes | Yes
Summary of IBIS Check
File Header
In column Pass/Fail below mark each item PASS, FAIL, NA or EXCEPTION.
The IQ level is the highest level number for which all checks PASS.
The IQ level is FAIL if no level completely passes.
See IBIS Quality Specification for complete descriptions of the checks.
IQ Spec Reference | IQ LEVEL | Description | PASS/FAIL | Comments
2.1 | LEVEL 1 | IBIS file passes IBISCHK | PASS
Components
Components | IQ LEVEL | Comments
Packaged - MT40A2G4SA, MT40A1G8SA, MT40A512M16LY | 3
Bare Die - MT40A2G4Z11B, MT40A1G8Z11B, MT40A512M16Z11B | 3
Models
Models | IQ LEVEL | Comments
I/O - DQ_34_*, DQ_40_*, DQ_48_*, DQS_34_*, DQS_40_*, DQS_48_* | 3MSX
Input - DQ_IN_, DQS_IN_, DM_*, INPUT, CLKIN, RESET, TEN | 3MS
Teminator - TDQS_*, NF_DQ , NF_INPUT | 3MS
Open_sink - ALERT | 3MS

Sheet: components(pkg)
COMPONENT(S): | MT40A2G4SA, MT40A1G8SA, MT40A512M16LY, MT40A2G4Z11B, MT40A1G8Z11B, MT40A512M16Z11B
IQ Level: | 3
Exception:
Correlation:
In column Pass/Fail below mark each item PASS, FAIL, NA or EXCEPTION.
The IQ level is the highest level number for which all checks PASS.
The IQ level is FAIL if no level completely passes.
See IBIS Quality Specification for complete descriptions of the checks.
IQ Spec Reference | IQ LEVEL | Description | PASS/FAIL | Comments
3.1.1 | LEVEL 2 | [Package] must have typ/min/max values | PASS
3.1.2 | LEVEL 2 | [Package] parasitics must be reasonable | PASS
3.2.1 | LEVEL 2 | [Pin] section complete | PASS
3.2.2 | LEVEL 3 | [Pin] RLC parasitics are present and reasonable | PASS
3.3.1 | LEVEL 2 | [Diff Pin] referenced pin models matched | PASS
3.3.2 | LEVEL 3 | [Diff Pin] Vdiff and Tdelay_* complete and reasonable | PASS
4.1 | LEVEL 2 | [Model Selector] entries have reasonable descriptions | PASS
4.2 | LEVEL 2 | Default [Model Selector] entries are consistent | PASS

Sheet: models(IO)
MODEL(S): | DQ_34_*, DQ_40_*, DQ_48_*, DQS_34_*, DQS_40_*, DQS_48_*
IQ Level: | 3
Exception: | 5.4.3 | V-t length is excessive due to inclusion of [Composite Current] I-t data.
Correlation: | MSX | Measuremant and Simulation Correlated
In column Pass/Fail below mark each item PASS, FAIL, NA or EXCEPTION.
The IQ level is the highest level number for which all checks PASS.
The IQ level is FAIL if no level completely passes.
See IBIS Quality Specification for complete descriptions of the checks.
IQ Spec Reference | IQ LEVEL | Description | PASS/FAIL | Comments
5.1.1 | LEVEL 2 | [Model] parameters have correct typ/min/max order | PASS
5.1.2 | LEVEL 2 | [Model] C_comp is reasonable | PASS
5.1.3 | LEVEL 2 | [Temperature Range] is reasonable | PASS
5.1.4 | LEVEL 2 | [Voltage Range] or [* Reference] is reasonable | PASS
5.2.1 | LEVEL 3 | [Model] Vinl and Vinh reasonable | PASS
5.2.2 | LEVEL 3 | [Model Spec] Vinl and Vinh reasonable | PASS
5.2.3 | LEVEL 3 | [Model Spec] Vinl+/- and Vinh+/- complete and reasonable | NA
5.2.5 | LEVEL 2 | [Model Spec] S_Overshoot subparameters complete and match data sheet | PASS
5.2.6 | LEVEL 2 | [Model Spec] S_Overshoot subparameters track typ/min/max | PASS
5.2.7 | LEVEL 2 | [Model Spec] D_Overshoot_* subparameters complete and match data sheet | PASS
5.2.8 | LEVEL 2 | [Model Spec] D_Overshoot_* subparameters track typ/min/max | PASS
5.2.9 | LEVEL 3 | [Receiver Thresholds] Vth present and matches data sheet, if needed | NA
5.2.10 | LEVEL 3 | [Receiver Thresholds] Vth_min and Vth_max present and match data sheet, if needed | NA
5.2.11 | LEVEL 3 | [Receiver Thresholds] Vinh_ac, Vinl_ac present and match data sheet, if needed | NA
5.2.12 | LEVEL 3 | [Receiver Thresholds] Vinh_dc, Vinl_dc present and match data sheet, if needed | NA
5.2.13 | LEVEL 3 | [Receiver Thresholds] Tslew_ac/Tdiffslew_ac present and match data sheet, if needed | NA
5.2.14 | LEVEL 3 | [Receiver Thresholds] Threshold_sensitivity and Ext_ref present and match data sheet, if needed | NA
5.3.1 | LEVEL 2 | I-V tables have correct typ/min/max order | PASS
5.3.2 | LEVEL 2 | [Pullup] voltage sweep range is correct | PASS
5.3.3 | LEVEL 2 | [Pulldown] voltage sweep range is correct | PASS
5.3.4 | LEVEL 2 | [POWER Clamp] voltage sweep range is correct | PASS
5.3.5 | LEVEL 2 | [GND Clamp] voltage sweep range is correct | PASS
5.3.6 | LEVEL 2 | I-V tables do not exhibit stair-stepping | PASS
5.3.7 | LEVEL 2 | Combined I-V tables are monotonic | PASS
5.3.8 | LEVEL 2 | [Pulldown] I-V tables pass through zero/zero | PASS
5.3.9 | LEVEL 2 | [Pullup] I-V tables pass through zero/zero | PASS
5.3.10 | LEVEL 2 | No leakage current in clamp I-V tables | PASS
5.3.11 | LEVEL 2 | I-V behavior not double-counted | PASS
5.3.12 | LEVEL 2 | On-die termination modeling documented | PASS
5.3.13 | LEVEL 2 | ECL models I-V tables swept from -Vcc to +2 * Vcc. | NA
5.3.14 | LEVEL 2 | Point distributions in I-V tables should be sufficient | PASS
5.4.1 | LEVEL 2 | Output and I/O buffers have sufficient V-T tables | PASS
5.4.2 | LEVEL 2 | V-T tables have reasonable point distribution | PASS
5.4.3 | LEVEL 3 | V-T table duration is not excessive | EXCEPTION | V-t length is long due to inclusion of [Composite Current] I-t data.
5.4.4 | LEVEL 2 | V-T table endpoints match fixture voltages | PASS
5.5.1 | LEVEL 2 | [Ramp] R_load present if value other than 50 ohms | PASS
5.5.2 | LEVEL 2 | [Ramp] typ/min/max order is correct | PASS
5.5.3 | LEVEL 2 | [Ramp] dV consistent with I-V table calculations | PASS
5.5.4 | LEVEL 2 | [Ramp] dt is consistent with 20%-80% crossing time | PASS
5.6.1 | LEVEL 3 | [Model Spec] Vmeas and Vref used if typ/min/max variation | PASS
5.6.2 | LEVEL 3 | Vref consistent for Open-drain, Open-source, and ECL Model_types | NA

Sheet: models(Input)
MODEL(S): | DQ_IN_, DQS_IN_, DM_*, INPUT, CLKIN, RESET, TEN
IQ Level: | 3
Exception:
Correlation: | MS | Measurement and Simulation Correlated
In column Pass/Fail below mark each item PASS, FAIL, NA or EXCEPTION.
The IQ level is the highest level number for which all checks PASS.
The IQ level is FAIL if no level completely passes.
See IBIS Quality Specification for complete descriptions of the checks.
IQ Spec Reference | IQ LEVEL | Description | PASS/FAIL | Comments
5.1.1 | LEVEL 2 | [Model] parameters have correct typ/min/max order | PASS
5.1.2 | LEVEL 2 | [Model] C_comp is reasonable | PASS
5.1.3 | LEVEL 2 | [Temperature Range] is reasonable | PASS
5.1.4 | LEVEL 2 | [Voltage Range] or [* Reference] is reasonable | PASS
5.2.1 | LEVEL 3 | [Model] Vinl and Vinh reasonable | PASS
5.2.2 | LEVEL 3 | [Model Spec] Vinl and Vinh reasonable | PASS
5.2.3 | LEVEL 3 | [Model Spec] Vinl+/- and Vinh+/- complete and reasonable | NA
5.2.5 | LEVEL 2 | [Model Spec] S_Overshoot subparameters complete and match data sheet | PASS
5.2.6 | LEVEL 2 | [Model Spec] S_Overshoot subparameters track typ/min/max | PASS
5.2.7 | LEVEL 2 | [Model Spec] D_Overshoot_* subparameters complete and match data sheet | PASS
5.2.8 | LEVEL 2 | [Model Spec] D_Overshoot_* subparameters track typ/min/max | PASS
5.2.9 | LEVEL 3 | [Receiver Thresholds] Vth present and matches data sheet, if needed | PASS
5.2.10 | LEVEL 3 | [Receiver Thresholds] Vth_min and Vth_max present and match data sheet, if needed | PASS
5.2.11 | LEVEL 3 | [Receiver Thresholds] Vinh_ac, Vinl_ac present and match data sheet, if needed | PASS
5.2.12 | LEVEL 3 | [Receiver Thresholds] Vinh_dc, Vinl_dc present and match data sheet, if needed | PASS
5.2.13 | LEVEL 3 | [Receiver Thresholds] Tslew_ac/Tdiffslew_ac present and match data sheet, if needed | PASS
5.2.14 | LEVEL 3 | [Receiver Thresholds] Threshold_sensitivity and Ext_ref present and match data sheet, if needed | PASS
5.3.1 | LEVEL 2 | I-V tables have correct typ/min/max order | PASS
5.3.2 | LEVEL 2 | [Pullup] voltage sweep range is correct | NA
5.3.3 | LEVEL 2 | [Pulldown] voltage sweep range is correct | NA
5.3.4 | LEVEL 2 | [POWER Clamp] voltage sweep range is correct | PASS
5.3.5 | LEVEL 2 | [GND Clamp] voltage sweep range is correct | PASS
5.3.6 | LEVEL 2 | I-V tables do not exhibit stair-stepping | PASS
5.3.7 | LEVEL 2 | Combined I-V tables are monotonic | PASS
5.3.8 | LEVEL 2 | [Pulldown] I-V tables pass through zero/zero | NA
5.3.9 | LEVEL 2 | [Pullup] I-V tables pass through zero/zero | NA
5.3.10 | LEVEL 2 | No leakage current in clamp I-V tables | PASS
5.3.11 | LEVEL 2 | I-V behavior not double-counted | PASS
5.3.12 | LEVEL 2 | On-die termination modeling documented | PASS
5.3.13 | LEVEL 2 | ECL models I-V tables swept from -Vcc to +2 * Vcc. | NA
5.3.14 | LEVEL 2 | Point distributions in I-V tables should be sufficient | PASS
5.4.1 | LEVEL 2 | Output and I/O buffers have sufficient V-T tables | NA
5.4.2 | LEVEL 2 | V-T tables have reasonable point distribution | NA
5.4.3 | LEVEL 3 | V-T table duration is not excessive | NA
5.4.4 | LEVEL 2 | V-T table endpoints match fixture voltages | NA
5.5.1 | LEVEL 2 | [Ramp] R_load present if value other than 50 ohms | NA
5.5.2 | LEVEL 2 | [Ramp] typ/min/max order is correct | NA
5.5.3 | LEVEL 2 | [Ramp] dV consistent with I-V table calculations | NA
5.5.4 | LEVEL 2 | [Ramp] dt is consistent with 20%-80% crossing time | NA
5.6.1 | LEVEL 3 | [Model Spec] Vmeas and Vref used if typ/min/max variation | NA
5.6.2 | LEVEL 3 | Vref consistent for Open-drain, Open-source, and ECL Model_types | NA

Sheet: models(Terminator)
MODEL(S): | TDQS_*, NF_DQ , NF_INPUT
IQ Level: | 3
Exception:
Correlation: | MS | Measurement and Simulation Correlated
In column Pass/Fail below mark each item PASS, FAIL, NA or EXCEPTION.
The IQ level is the highest level number for which all checks PASS.
The IQ level is FAIL if no level completely passes.
See IBIS Quality Specification for complete descriptions of the checks.
IQ Spec Reference | IQ LEVEL | Description | PASS/FAIL | Comments
5.1.1 | LEVEL 2 | [Model] parameters have correct typ/min/max order | PASS
5.1.2 | LEVEL 2 | [Model] C_comp is reasonable | PASS
5.1.3 | LEVEL 2 | [Temperature Range] is reasonable | PASS
5.1.4 | LEVEL 2 | [Voltage Range] or [* Reference] is reasonable | PASS
5.2.1 | LEVEL 3 | [Model] Vinl and Vinh reasonable | NA
5.2.2 | LEVEL 3 | [Model Spec] Vinl and Vinh reasonable | NA
5.2.3 | LEVEL 3 | [Model Spec] Vinl+/- and Vinh+/- complete and reasonable | NA
5.2.5 | LEVEL 2 | [Model Spec] S_Overshoot subparameters complete and match data sheet | NA
5.2.6 | LEVEL 2 | [Model Spec] S_Overshoot subparameters track typ/min/max | NA
5.2.7 | LEVEL 2 | [Model Spec] D_Overshoot_* subparameters complete and match data sheet | NA
5.2.8 | LEVEL 2 | [Model Spec] D_Overshoot_* subparameters track typ/min/max | NA
5.2.9 | LEVEL 3 | [Receiver Thresholds] Vth present and matches data sheet, if needed | NA
5.2.10 | LEVEL 3 | [Receiver Thresholds] Vth_min and Vth_max present and match data sheet, if needed | NA
5.2.11 | LEVEL 3 | [Receiver Thresholds] Vinh_ac, Vinl_ac present and match data sheet, if needed | NA
5.2.12 | LEVEL 3 | [Receiver Thresholds] Vinh_dc, Vinl_dc present and match data sheet, if needed | NA
5.2.13 | LEVEL 3 | [Receiver Thresholds] Tslew_ac/Tdiffslew_ac present and match data sheet, if needed | NA
5.2.14 | LEVEL 3 | [Receiver Thresholds] Threshold_sensitivity and Ext_ref present and match data sheet, if needed | NA
5.3.1 | LEVEL 2 | I-V tables have correct typ/min/max order | PASS
5.3.2 | LEVEL 2 | [Pullup] voltage sweep range is correct | NA
5.3.3 | LEVEL 2 | [Pulldown] voltage sweep range is correct | NA
5.3.4 | LEVEL 2 | [POWER Clamp] voltage sweep range is correct | PASS
5.3.5 | LEVEL 2 | [GND Clamp] voltage sweep range is correct | PASS
5.3.6 | LEVEL 2 | I-V tables do not exhibit stair-stepping | PASS
5.3.7 | LEVEL 2 | Combined I-V tables are monotonic | PASS
5.3.8 | LEVEL 2 | [Pulldown] I-V tables pass through zero/zero | NA
5.3.9 | LEVEL 2 | [Pullup] I-V tables pass through zero/zero | NA
5.3.10 | LEVEL 2 | No leakage current in clamp I-V tables | PASS
5.3.11 | LEVEL 2 | I-V behavior not double-counted | PASS
5.3.12 | LEVEL 2 | On-die termination modeling documented | PASS
5.3.13 | LEVEL 2 | ECL models I-V tables swept from -Vcc to +2 * Vcc. | NA
5.3.14 | LEVEL 2 | Point distributions in I-V tables should be sufficient | PASS
5.4.1 | LEVEL 2 | Output and I/O buffers have sufficient V-T tables | NA
5.4.2 | LEVEL 2 | V-T tables have reasonable point distribution | NA
5.4.3 | LEVEL 3 | V-T table duration is not excessive | NA
5.4.4 | LEVEL 2 | V-T table endpoints match fixture voltages | NA
5.5.1 | LEVEL 2 | [Ramp] R_load present if value other than 50 ohms | NA
5.5.2 | LEVEL 2 | [Ramp] typ/min/max order is correct | NA
5.5.3 | LEVEL 2 | [Ramp] dV consistent with I-V table calculations | NA
5.5.4 | LEVEL 2 | [Ramp] dt is consistent with 20%-80% crossing time | NA
5.6.1 | LEVEL 3 | [Model Spec] Vmeas and Vref used if typ/min/max variation | NA
5.6.2 | LEVEL 3 | Vref consistent for Open-drain, Open-source, and ECL Model_types | NA

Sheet: models(Open_drain)
MODEL(S): | ALERT
IQ Level: | 3
Exception:
Correlation: | MS | Measurement and Simulation Correlated
In column Pass/Fail below mark each item PASS, FAIL, NA or EXCEPTION.
The IQ level is the highest level number for which all checks PASS.
The IQ level is FAIL if no level completely passes.
See IBIS Quality Specification for complete descriptions of the checks.
IQ Spec Reference | IQ LEVEL | Description | PASS/FAIL | Comments
5.1.1 | LEVEL 2 | [Model] parameters have correct typ/min/max order | PASS
5.1.2 | LEVEL 2 | [Model] C_comp is reasonable | PASS
5.1.3 | LEVEL 2 | [Temperature Range] is reasonable | PASS
5.1.4 | LEVEL 2 | [Voltage Range] or [* Reference] is reasonable | PASS
5.2.1 | LEVEL 3 | [Model] Vinl and Vinh reasonable | NA
5.2.2 | LEVEL 3 | [Model Spec] Vinl and Vinh reasonable | NA
5.2.3 | LEVEL 3 | [Model Spec] Vinl+/- and Vinh+/- complete and reasonable | NA
5.2.5 | LEVEL 2 | [Model Spec] S_Overshoot subparameters complete and match data sheet | NA
5.2.6 | LEVEL 2 | [Model Spec] S_Overshoot subparameters track typ/min/max | NA
5.2.7 | LEVEL 2 | [Model Spec] D_Overshoot_* subparameters complete and match data sheet | NA
5.2.8 | LEVEL 2 | [Model Spec] D_Overshoot_* subparameters track typ/min/max | NA
5.2.9 | LEVEL 3 | [Receiver Thresholds] Vth present and matches data sheet, if needed | NA
5.2.10 | LEVEL 3 | [Receiver Thresholds] Vth_min and Vth_max present and match data sheet, if needed | NA
5.2.11 | LEVEL 3 | [Receiver Thresholds] Vinh_ac, Vinl_ac present and match data sheet, if needed | NA
5.2.12 | LEVEL 3 | [Receiver Thresholds] Vinh_dc, Vinl_dc present and match data sheet, if needed | NA
5.2.13 | LEVEL 3 | [Receiver Thresholds] Tslew_ac/Tdiffslew_ac present and match data sheet, if needed | NA
5.2.14 | LEVEL 3 | [Receiver Thresholds] Threshold_sensitivity and Ext_ref present and match data sheet, if needed | NA
5.3.1 | LEVEL 2 | I-V tables have correct typ/min/max order | PASS
5.3.2 | LEVEL 2 | [Pullup] voltage sweep range is correct | NA
5.3.3 | LEVEL 2 | [Pulldown] voltage sweep range is correct | PASS
5.3.4 | LEVEL 2 | [POWER Clamp] voltage sweep range is correct | PASS
5.3.5 | LEVEL 2 | [GND Clamp] voltage sweep range is correct | PASS
5.3.6 | LEVEL 2 | I-V tables do not exhibit stair-stepping | PASS
5.3.7 | LEVEL 2 | Combined I-V tables are monotonic | PASS
5.3.8 | LEVEL 2 | [Pulldown] I-V tables pass through zero/zero | PASS
5.3.9 | LEVEL 2 | [Pullup] I-V tables pass through zero/zero | NA
5.3.10 | LEVEL 2 | No leakage current in clamp I-V tables | PASS
5.3.11 | LEVEL 2 | I-V behavior not double-counted | PASS
5.3.12 | LEVEL 2 | On-die termination modeling documented | NA
5.3.13 | LEVEL 2 | ECL models I-V tables swept from -Vcc to +2 * Vcc. | NA
5.3.14 | LEVEL 2 | Point distributions in I-V tables should be sufficient | PASS
5.4.1 | LEVEL 2 | Output and I/O buffers have sufficient V-T tables | PASS
5.4.2 | LEVEL 2 | V-T tables have reasonable point distribution | PASS
5.4.3 | LEVEL 3 | V-T table duration is not excessive | PASS
5.4.4 | LEVEL 2 | V-T table endpoints match fixture voltages | PASS
5.5.1 | LEVEL 2 | [Ramp] R_load present if value other than 50 ohms | PASS
5.5.2 | LEVEL 2 | [Ramp] typ/min/max order is correct | PASS
5.5.3 | LEVEL 2 | [Ramp] dV consistent with I-V table calculations | PASS
5.5.4 | LEVEL 2 | [Ramp] dt is consistent with 20%-80% crossing time | PASS
5.6.1 | LEVEL 3 | [Model Spec] Vmeas and Vref used if typ/min/max variation | PASS
5.6.2 | LEVEL 3 | Vref consistent for Open-drain, Open-source, and ECL Model_types | PASS

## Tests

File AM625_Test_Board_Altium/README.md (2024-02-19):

1.1 has a different footprint for the Micro SD card, based on supply.

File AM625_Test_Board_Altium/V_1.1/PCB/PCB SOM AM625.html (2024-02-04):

Altium customize

# Board Information Report

Date: | | 12/25/2023
Time: | | 11:34:14 PM
Elapsed Time: | | 00:00:01
Filename: | | D:\HUST\02.OS\05.Project Board Test SOM AM625_2512\PCB\PCB SOM AM625.PcbDoc
Units: | | mmmils

## Contents

Contents

Board Specification

General

Routing

Routing Information

Layer Information

Layer Information

Drill Pairs

Copper Area

Copper Area

Board Holes

Non-Plated Hole Size

Plated Hole Size

Board Slots

Non-Plated Slot Size

Plated Slot Size

Board Square Holes

Non-Plated Square Hole Size

Plated Square Hole Size

Other

Top Layer Annular Ring Size

Mid Layer Annular Ring Size

Bottom Layer Annular Ring Size

Pad Solder Mask

Pad Paste Mask

Pad Pwr/Gnd Expansion

Pad Relief Conductor Width

Pad Relief Air Gap

Pad Relief Entries

Via Solder Mask

Track Width

Arc Line Width

Arc Radius

Arc Degrees

Text Height

Text Width

Net Track Width

Net Via Size

## Board Specification

General
Board Size | 152.4mm x 101.6mm
Components on board | 380

Back to top

## Routing

Routing Information
Routing completion | 12.13%
Connections | 1113
Connections routed | 135
Connections remaining | 978

Back to top

## Layer Information

Layer | Arcs | Pads | Vias | Tracks | Texts | Fills | Regions | ComponentBodies
Top Layer | 0 | 1260 | 0 | 0 | 0 | 0 | 12 | 0
Bottom Layer | 0 | 136 | 0 | 0 | 0 | 0 | 0 | 0
Mechanical 1 | 4 | 0 | 0 | 7 | 3 | 0 | 0 | 427
Top Assembly | 0 | 0 | 0 | 0 | 0 | 0 | 0 | 0
Top Value | 0 | 0 | 0 | 0 | 0 | 0 | 0 | 0
Mechanical 13 | 4 | 0 | 0 | 446 | 0 | 0 | 0 | 2
Mechanical 15 | 0 | 0 | 0 | 196 | 0 | 0 | 1 | 0
Mechanical 17 | 0 | 0 | 0 | 30 | 0 | 0 | 0 | 0
Mechanical 19 | 0 | 0 | 0 | 315 | 58 | 0 | 1 | 0
Bottom Value | 2 | 0 | 0 | 72 | 0 | 0 | 0 | 0
Mechanical 24 | 0 | 0 | 0 | 4 | 0 | 0 | 0 | 0
Mechanical 29 | 3 | 0 | 0 | 381 | 334 | 0 | 0 | 4
Bottom Assembly | 0 | 0 | 0 | 0 | 0 | 0 | 0 | 0
Multi-Layer | 0 | 263 | 0 | 4 | 0 | 0 | 4 | 0
Top Paste | 0 | 0 | 0 | 0 | 0 | 0 | 118 | 0
Top Overlay | 70 | 0 | 0 | 383 | 760 | 0 | 0 | 0
Top Solder | 0 | 0 | 0 | 0 | 0 | 0 | 106 | 0
Bottom Solder | 0 | 0 | 0 | 0 | 0 | 0 | 0 | 0
Bottom Overlay | 0 | 0 | 0 | 0 | 0 | 0 | 0 | 0
Bottom Paste | 0 | 0 | 0 | 0 | 0 | 0 | 0 | 0
Drill Guide | 0 | 0 | 0 | 0 | 0 | 0 | 0 | 0
Keep-Out Layer | 0 | 0 | 0 | 0 | 0 | 0 | 1 | 0
Drill Drawing | 0 | 0 | 0 | 0 | 0 | 0 | 0 | 0
Total | 83 | 1659 | 0 | 1838 | 1155 | 0 | 243 | 433

Back to top

Drill Pairs | Vias
Total | 0

Back to top

## Copper Area

Layer | Sq.In. | Sq.MM. | Percent of layer
Top Layer | 1.143 | 737.427 | 5%
Bottom Layer | 0.397 | 256.052 | 2%
Total | 1.54 | 993.479

Back to top

## Board Holes

Non-Plated Hole Size | Pads | Vias
0mm | 244 | 0
0.6096mm | 8 | 0
0.6604mm | 2 | 0
0.9mm | 2 | 0
1.1mm | 2 | 0
1.1999mm | 3 | 0
Total | 261 | 0

Back to top

Plated Hole Size | Pads | Vias
0mm | 1152 | 0
0.254mm | 36 | 0
0.4mm | 134 | 0
0.5mm | 1 | 0
0.9mm | 33 | 0
0.97mm | 4 | 0
1mm | 4 | 0
1.0668mm | 7 | 0
1.1mm | 4 | 0
1.3mm | 9 | 0
1.6002mm | 2 | 0
2mm | 2 | 0
3mm | 2 | 0
3.3mm | 2 | 0
Total | 1392 | 0

Back to top

## Board Slots

Non-Plated Slot Size / Length | Pads
Total | 0

Back to top

Plated Slot Size / Length | Pads
37.402mil / 92.52mil | 2
Total | 2

Back to top

## Board Square Holes

Non-Plated Square Hole Size | Pads
0.75mm | 2
1mm | 2
Total | 4

Back to top

Plated Square Hole Size | Pads
Total | 0

Back to top

## Other

Top Layer Annular Ring Size | Count
-3.3mm | 2
-0.39mm | 2
-0.14mm | 2
0mm | 16
0.0004mm | 1
0.254mm | 36
0.3mm | 1
0.4mm | 134
0.508mm | 4
0.55mm | 4
0.5842mm | 7
0.6mm | 21
0.605mm | 5
0.624mm | 12
0.8mm | 4
0.9mm | 4
0.9398mm | 2
1mm | 2
1mm | 2
1.966mm | 2
Total | 263

Back to top

Mid Layer Annular Ring Size | Count
-3.3mm | 2
-0.39mm | 2
-0.14mm | 2
0mm | 7
0.3mm | 1
0.4mm | 134
0.508mm | 4
0.55mm | 4
0.5842mm | 7
0.6mm | 21
0.605mm | 5
0.624mm | 12
0.8mm | 4
0.8636mm | 2
0.9mm | 4
0.9144mm | 8
0.9398mm | 2
1mm | 2
1mm | 2
1.27mm | 36
1.966mm | 2
Total | 263

Back to top

Bottom Layer Annular Ring Size | Count
-3.3mm | 2
-0.39mm | 2
-0.14mm | 2
0mm | 17
0.254mm | 36
0.3mm | 1
0.4mm | 134
0.508mm | 4
0.55mm | 4
0.5842mm | 7
0.6mm | 21
0.605mm | 5
0.624mm | 12
0.8mm | 4
0.9mm | 4
0.9398mm | 2
1mm | 2
1mm | 2
1.966mm | 2
Total | 263

Back to top

Pad Solder Mask | Count
-2.5654mm | 1
-0.4191mm | 48
-0.254mm | 36
0mm | 78
0.0254mm | 19
0.04mm | 202
0.05mm | 153
0.0508mm | 1
0.1016mm | 1121
Total | 1659

Back to top

Pad Paste Mask | Count
-4mm | 1
-2.5623mm | 1
-2mm | 1
-1.0541mm | 2
-1mm | 10
-0.9017mm | 2
-0.635mm | 1
-0.4123mm | 48
-0.3302mm | 2
-0.3048mm | 12
-0.254mm | 36
0mm | 1543
Total | 1659

Back to top

Pad Pwr/Gnd Expansion | Count
0.508mm | 1659
Total | 1659

Back to top

Pad Relief Conductor Width | Count
0.254mm | 1659
Total | 1659

Back to top

Pad Relief Air Gap | Count
0.254mm | 1659
Total | 1659

Back to top

Pad Relief Entries | Count
4 | 1659
Total | 1659

Back to top

Via Solder Mask | Count
Total | 0

Back to top

Track Width | Count
0mm | 234
0.0001mm | 3
0.0254mm | 114
0.05mm | 235
0.1mm | 755
0.127mm | 187
0.15mm | 20
0.1524mm | 32
0.1778mm | 4
0.2mm | 231
0.2032mm | 7
0.254mm | 12
0.6096mm | 4
Total | 1838

Back to top

Arc Line Width | Count
0mm | 6
0.0254mm | 2
0.127mm | 2
0.15mm | 26
0.1524mm | 8
0.1999mm | 1
0.2mm | 14
0.254mm | 4
0.3mm | 2
0.4mm | 16
0.508mm | 2
Total | 83

Back to top

Arc Radius | Count
0.02mm | 13
0.075mm | 26
0.0762mm | 8
0.1mm | 12
0.127mm | 5
0.1632mm | 2
0.2mm | 1
0.2074mm | 2
0.3048mm | 2
0.326mm | 2
0.3409mm | 2
0.381mm | 2
0.4mm | 4
2.8086mm | 1
12.7mm | 1
Total | 83

Back to top

Arc Degrees | Count
21 | 2
90 | 6
180 | 2
360 | 73
Total | 83

Back to top

Text Height | Count
0.5mm | 3
0.6mm | 116
1mm | 232
1.2mm | 2
1.524mm | 762
3mm | 40
Total | 1155

Back to top

Text Width | Count
0.1mm | 119
0.23mm | 2
0.254mm | 1034
Total | 1155

Back to top

Net Track Width | Count
0.254mm | 325
Total | 325

Back to top

Net Via Size | Count
1.27mm | 325
Total | 325

Back to top

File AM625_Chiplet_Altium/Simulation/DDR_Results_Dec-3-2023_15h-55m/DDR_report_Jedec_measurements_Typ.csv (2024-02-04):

Net Name | Pass/Fail | Operation | Driver Comp Ref Des & Pin Name | Receiver Comp Ref Des & Pin Name | Rise Rail Overshoot, [mV] | Rise Rail Overshoot Limit, [mV] | Rise Rail Overshoot Margin, [mV] | Rise Rail Overshoot, [Pass/Fail] | Rise Rail Overshoot Trace Point, [ns] | Fall Rail Undershoot, [mV] | Fall Rail Undershoot Limit, [mV] | Fall Rail Undershoot Margin, [mV] | Fall Rail Undershoot, [Pass/Fail] | Fall Rail Undershoot Trace Point, [ns] | Rise Rail Overshoot Area, [V*ns] | Rise Rail Overshoot Area Limit, [V*ns] | Rise Rail Overshoot Area Margin, [V*ns] | Rise Rail Overshoot Area, [Pass/Fail] | Rise Rail Overshoot Area Trace Point, [ns] | Fall Rail Undershoot Area, [V*ns] | Fall Rail Undershoot Area Limit, [V*ns] | Fall Rail Undershoot Area Margin, [V*ns] | Fall Rail Undershoot Area, [Pass/Fail] | Fall Rail Undershoot Area Trace Point, [ns] | Rise Rail Overshoot Area (2), [V*ns] | Rise Rail Overshoot Area (2) Limit, [V*ns] | Rise Rail Overshoot Area (2) Margin, [V*ns] | Rise Rail Overshoot Area (2), [Pass/Fail] | Rise Rail Overshoot Area (2) Trace Point, [ns] | Fall Rail Undershoot Area (2), [V*ns] | Fall Rail Undershoot Area (2) Limit, [V*ns] | Fall Rail Undershoot Area (2) Margin, [V*ns] | Fall Rail Undershoot Area (2), [Pass/Fail] | Fall Rail Undershoot Area (2) Trace Point, [ns] | Monotonic, [Pass/Fail] | Monotonic Trace Point, [ns] | VIH/L(AC) Min Limit, [Pass/Fail] | VIH/L(AC) Min Limit, Trace Point, [ns] | VIH/L(DC) Monotonicity, [Pass/Fail] | VIH/L(DC) Monotonicity Trace Point, [ns] | Vref Threshold Multi Cross, [Pass/Fail] | Max Slew Time, [ps] | Max Slew Time, [Pass/Fail] | VIX Limit Low, mV | VIX Limit Hi, mV | VIX Margin, mV | VIX, [Pass/Fail] | VIX Trace Point, [ns] | VID(AC) Limit, mV | VID(AC) Margin, mV | VID(AC), [Pass/Fail] | VID(AC) Trace Point, [ns] | VID(DC) Limit, mV | VID(DC), [Pass/Fail] | VID(DC) Trace Point, [ns] | Vdd/2, mV | VSEL Limit, mV | VSEL Margin, mV | VSEL, [Pass/Fail]
DDR_CLK_P | Pass | Write rank(1,1) | U1.L1&L2 | U2.K7&K8 | 0.0 | 300.0 | 300.0 | Pass | N/A | 0.0 | 300.0 | 300.0 | Pass | N/A | 0.0000 | 0.1125 | 0.1125 | Pass | N/A | 0.0000 | 0.1144 | 0.1144 | Pass | N/A | 0.0000 | 0.0038 | 0.0038 | Pass | N/A | N/A | N/A | N/A | N/A | N/A | Pass | N/A | N/A | N/A | N/A | N/A | Pass | 41.9 | Pass | 480.0 | 720.0 | 92.0 | Pass | 78.535 | 180.0 | 547.9 | Pass | 1.971 | 150.0 | Pass | N/A | 600.0 | 500.0 | 278.1 | Pass
DDR_LDQS_P | Pass | Write rank(1,1) | U1.E1&E2 | U2.G3&F3 | 27.1 | 400.0 | 372.9 | Pass | 2.729 | 0.0 | 400.0 | 400.0 | Pass | N/A | 0.0031 | 0.1050 | 0.1019 | Pass | 80.240 | 0.0000 | 0.1050 | 0.1050 | Pass | N/A | 0.0000 | 0.0150 | 0.0150 | Pass | N/A | 0.0000 | 0.0150 | 0.0150 | Pass | N/A | Pass | N/A | N/A | N/A | N/A | N/A | Pass | N/A | N/A | 671.8 | 1025.0 | 161.6 | Pass | 1.705 | N/A | N/A | N/A | N/A | N/A | N/A | N/A | N/A | N/A | N/A | N/A
DDR_UDQS_P | Pass | Write rank(1,1) | U1.V1&V2 | U2.B7&A7 | 25.6 | 400.0 | 374.4 | Pass | 2.108 | 0.0 | 400.0 | 400.0 | Pass | N/A | 0.0028 | 0.1050 | 0.1022 | Pass | 2.054 | 0.0000 | 0.1050 | 0.1050 | Pass | N/A | 0.0000 | 0.0150 | 0.0150 | Pass | N/A | 0.0000 | 0.0150 | 0.0150 | Pass | N/A | Pass | N/A | N/A | N/A | N/A | N/A | Pass | N/A | N/A | 683.0 | 1021.5 | 153.7 | Pass | 38.553 | N/A | N/A | N/A | N/A | N/A | N/A | N/A | N/A | N/A | N/A | N/A
DDR_A0 | Pass | Write rank(1,1) | U1.J1 | U2.P3 | 146.6 | 300.0 | 153.4 | Pass | 43.407 | 206.9 | 300.0 | 93.1 | Pass | 44.647 | 0.0347 | 0.2550 | 0.2203 | Pass | 58.309 | 0.0615 | 0.2644 | 0.2029 | Pass | 30.799 | 0.0000 | 0.0083 | 0.0083 | Pass | N/A | N/A | N/A | N/A | N/A | N/A | Pass | N/A | Pass | N/A | Pass | N/A | Pass | 27.9 | Pass | N/A | N/A | N/A | N/A | N/A | N/A | N/A | N/A | N/A | N/A | N/A | N/A | N/A | N/A | N/A | N/A
DDR_A1 | Pass | Write rank(1,1) | U1.J2 | U2.P7 | 205.0 | 300.0 | 95.0 | Pass | 68.419 | 269.4 | 300.0 | 30.6 | Pass | 40.903 | 0.0423 | 0.2550 | 0.2127 | Pass | 79.585 | 0.0677 | 0.2644 | 0.1967 | Pass | 67.069 | 0.0000 | 0.0083 | 0.0083 | Pass | N/A | N/A | N/A | N/A | N/A | N/A | Pass | N/A | Pass | N/A | Pass | N/A | Pass | 30.2 | Pass | N/A | N/A | N/A | N/A | N/A | N/A | N/A | N/A | N/A | N/A | N/A | N/A | N/A | N/A | N/A | N/A
DDR_A10 | Pass | Write rank(1,1) | U1.R5 | U2.M3 | 125.9 | 300.0 | 174.1 | Pass | 68.279 | 207.8 | 300.0 | 92.2 | Pass | 20.766 | 0.0262 | 0.2550 | 0.2288 | Pass | 68.269 | 0.0487 | 0.2644 | 0.2157 | Pass | 20.754 | 0.0000 | 0.0083 | 0.0083 | Pass | N/A | N/A | N/A | N/A | N/A | N/A | Pass | N/A | Pass | N/A | Pass | N/A | Pass | 30.2 | Pass | N/A | N/A | N/A | N/A | N/A | N/A | N/A | N/A | N/A | N/A | N/A | N/A | N/A | N/A | N/A | N/A
DDR_A11 | Pass | Write rank(1,1) | U1.P5 | U2.T2 | 141.4 | 300.0 | 158.6 | Pass | 62.051 | 218.5 | 300.0 | 81.5 | Pass | 7.036 | 0.0285 | 0.2550 | 0.2265 | Pass | 69.536 | 0.0507 | 0.2644 | 0.2137 | Pass | 78.270 | 0.0000 | 0.0083 | 0.0083 | Pass | N/A | N/A | N/A | N/A | N/A | N/A | Pass | N/A | Pass | N/A | Pass | N/A | Pass | 37.2 | Pass | N/A | N/A | N/A | N/A | N/A | N/A | N/A | N/A | N/A | N/A | N/A | N/A | N/A | N/A | N/A | N/A
DDR_A12 | Pass | Write rank(1,1) | U1.R6 | U2.M7 | 131.5 | 300.0 | 168.5 | Pass | 3.288 | 209.8 | 300.0 | 90.2 | Pass | 32.022 | 0.0269 | 0.2550 | 0.2281 | Pass | 3.268 | 0.0487 | 0.2644 | 0.2157 | Pass | 32.005 | 0.0000 | 0.0083 | 0.0083 | Pass | N/A | N/A | N/A | N/A | N/A | N/A | Pass | N/A | Pass | N/A | Pass | N/A | Pass | 32.6 | Pass | N/A | N/A | N/A | N/A | N/A | N/A | N/A | N/A | N/A | N/A | N/A | N/A | N/A | N/A | N/A | N/A
DDR_A13 | Pass | Write rank(1,1) | U1.R1 | U2.T8 | 162.3 | 300.0 | 137.7 | Pass | 78.445 | 214.4 | 300.0 | 85.6 | Pass | 9.681 | 0.0427 | 0.2550 | 0.2123 | Pass | 78.347 | 0.0706 | 0.2644 | 0.1938 | Pass | 9.585 | 0.0000 | 0.0083 | 0.0083 | Pass | N/A | N/A | N/A | N/A | N/A | N/A | Pass | N/A | Pass | N/A | Pass | N/A | Pass | 30.2 | Pass | N/A | N/A | N/A | N/A | N/A | N/A | N/A | N/A | N/A | N/A | N/A | N/A | N/A | N/A | N/A | N/A
DDR_A14_WEn | Pass | Write rank(1,1) | U1.N3 | U2.L2 | 127.1 | 300.0 | 172.9 | Pass | 24.623 | 199.6 | 300.0 | 100.4 | Pass | 45.864 | 0.0295 | 0.2550 | 0.2255 | Pass | 27.046 | 0.0532 | 0.2644 | 0.2112 | Pass | 62.031 | 0.0000 | 0.0083 | 0.0083 | Pass | N/A | N/A | N/A | N/A | N/A | N/A | Pass | N/A | Pass | N/A | Pass | N/A | Pass | 30.2 | Pass | N/A | N/A | N/A | N/A | N/A | N/A | N/A | N/A | N/A | N/A | N/A | N/A | N/A | N/A | N/A | N/A
DDR_A15_CAS | Pass | Write rank(1,1) | U1.M4 | U2.M8 | 151.4 | 300.0 | 148.6 | Pass | 4.560 | 217.4 | 300.0 | 82.6 | Pass | 63.300 | 0.0320 | 0.2550 | 0.2230 | Pass | 10.797 | 0.0538 | 0.2644 | 0.2106 | Pass | 27.032 | 0.0000 | 0.0083 | 0.0083 | Pass | N/A | N/A | N/A | N/A | N/A | N/A | Pass | N/A | Pass | N/A | Pass | N/A | Pass | 32.6 | Pass | N/A | N/A | N/A | N/A | N/A | N/A | N/A | N/A | N/A | N/A | N/A | N/A | N/A | N/A | N/A | N/A
DDR_A16_RAS | Pass | Write rank(1,1) | U1.M5 | U2.L8 | 155.5 | 300.0 | 144.5 | Pass | 54.561 | 224.1 | 300.0 | 75.9 | Pass | 39.549 | 0.0329 | 0.2550 | 0.2221 | Pass | 27.048 | 0.0566 | 0.2644 | 0.2078 | Pass | 25.780 | 0.0000 | 0.0083 | 0.0083 | Pass | N/A | N/A | N/A | N/A | N/A | N/A | Pass | N/A | Pass | N/A | Pass | N/A | Pass | 32.6 | Pass | N/A | N/A | N/A | N/A | N/A | N/A | N/A | N/A | N/A | N/A | N/A | N/A | N/A | N/A | N/A | N/A
DDR_A2 | Pass | Write rank(1,1) | U1.K3 | U2.R3 | 169.0 | 300.0 | 131.0 | Pass | 53.407 | 235.0 | 300.0 | 65.0 | Pass | 69.647 | 0.0392 | 0.2550 | 0.2158 | Pass | 53.326 | 0.0644 | 0.2644 | 0.2000 | Pass | 52.061 | 0.0000 | 0.0083 | 0.0083 | Pass | N/A | N/A | N/A | N/A | N/A | N/A | Pass | N/A | Pass | N/A | Pass | N/A | Pass | 30.2 | Pass | N/A | N/A | N/A | N/A | N/A | N/A | N/A | N/A | N/A | N/A | N/A | N/A | N/A | N/A | N/A | N/A
DDR_A3 | Pass | Write rank(1,1) | U1.L5 | U2.N7 | 146.3 | 300.0 | 153.7 | Pass | 48.298 | 218.4 | 300.0 | 81.6 | Pass | 62.039 | 0.0307 | 0.2550 | 0.2243 | Pass | 63.285 | 0.0535 | 0.2644 | 0.2109 | Pass | 42.020 | 0.0000 | 0.0083 | 0.0083 | Pass | N/A | N/A | N/A | N/A | N/A | N/A | Pass | N/A | Pass | N/A | Pass | N/A | Pass | 30.2 | Pass | N/A | N/A | N/A | N/A | N/A | N/A | N/A | N/A | N/A | N/A | N/A | N/A | N/A | N/A | N/A | N/A
DDR_A4 | Pass | Write rank(1,1) | U1.K4 | U2.N3 | 160.7 | 300.0 | 139.3 | Pass | 59.559 | 227.8 | 300.0 | 72.2 | Pass | 5.807 | 0.0349 | 0.2550 | 0.2201 | Pass | 59.550 | 0.0583 | 0.2644 | 0.2061 | Pass | 10.784 | 0.0000 | 0.0083 | 0.0083 | Pass | N/A | N/A | N/A | N/A | N/A | N/A | Pass | N/A | Pass | N/A | Pass | N/A | Pass | 30.2 | Pass | N/A | N/A | N/A | N/A | N/A | N/A | N/A | N/A | N/A | N/A | N/A | N/A | N/A | N/A | N/A | N/A
DDR_A5 | Pass | Write rank(1,1) | U1.K1 | U2.P8 | 165.1 | 300.0 | 134.9 | Pass | 27.215 | 216.6 | 300.0 | 83.4 | Pass | 40.955 | 0.0432 | 0.2550 | 0.2118 | Pass | 42.114 | 0.0706 | 0.2644 | 0.1938 | Pass | 3.353 | 0.0000 | 0.0083 | 0.0083 | Pass | N/A | N/A | N/A | N/A | N/A | N/A | Pass | N/A | Pass | N/A | Pass | N/A | Pass | 32.6 | Pass | N/A | N/A | N/A | N/A | N/A | N/A | N/A | N/A | N/A | N/A | N/A | N/A | N/A | N/A | N/A | N/A
DDR_A6 | Pass | Write rank(1,1) | U1.R2 | U2.P2 | 156.5 | 300.0 | 143.5 | Pass | 42.150 | 224.2 | 300.0 | 75.8 | Pass | 47.134 | 0.0354 | 0.2550 | 0.2196 | Pass | 4.574 | 0.0601 | 0.2644 | 0.2043 | Pass | 73.309 | 0.0000 | 0.0083 | 0.0083 | Pass | N/A | N/A | N/A | N/A | N/A | N/A | Pass | N/A | Pass | N/A | Pass | N/A | Pass | 27.9 | Pass | N/A | N/A | N/A | N/A | N/A | N/A | N/A | N/A | N/A | N/A | N/A | N/A | N/A | N/A | N/A | N/A
DDR_A7 | Pass | Write rank(1,1) | U1.P2 | U2.R8 | 179.9 | 300.0 | 120.1 | Pass | 22.190 | 235.7 | 300.0 | 64.3 | Pass | 35.929 | 0.0450 | 0.2550 | 0.2100 | Pass | 22.099 | 0.0710 | 0.2644 | 0.1934 | Pass | 42.090 | 0.0000 | 0.0083 | 0.0083 | Pass | N/A | N/A | N/A | N/A | N/A | N/A | Pass | N/A | Pass | N/A | Pass | N/A | Pass | 32.6 | Pass | N/A | N/A | N/A | N/A | N/A | N/A | N/A | N/A | N/A | N/A | N/A | N/A | N/A | N/A | N/A | N/A
DDR_A8 | Pass | Write rank(1,1) | U1.P1 | U2.R2 | 187.8 | 300.0 | 112.2 | Pass | 38.451 | 241.3 | 300.0 | 58.7 | Pass | 53.435 | 0.0489 | 0.2550 | 0.2061 | Pass | 48.360 | 0.0759 | 0.2644 | 0.1885 | Pass | 42.100 | 0.0000 | 0.0083 | 0.0083 | Pass | N/A | N/A | N/A | N/A | N/A | N/A | Pass | N/A | Pass | N/A | Pass | N/A | Pass | 30.2 | Pass | N/A | N/A | N/A | N/A | N/A | N/A | N/A | N/A | N/A | N/A | N/A | N/A | N/A | N/A | N/A | N/A
DDR_A9 | Pass | Write rank(1,1) | U1.P4 | U2.R7 | 153.1 | 300.0 | 146.9 | Pass | 15.805 | 219.0 | 300.0 | 81.0 | Pass | 73.298 | 0.0328 | 0.2550 | 0.2222 | Pass | 3.297 | 0.0549 | 0.2644 | 0.2095 | Pass | 62.031 | 0.0000 | 0.0083 | 0.0083 | Pass | N/A | N/A | N/A | N/A | N/A | N/A | Pass | N/A | Pass | N/A | Pass | N/A | Pass | 30.2 | Pass | N/A | N/A | N/A | N/A | N/A | N/A | N/A | N/A | N/A | N/A | N/A | N/A | N/A | N/A | N/A | N/A
DDR_ACTn | Pass | Write rank(1,1) | U1.N6 | U2.L3 | 111.6 | 300.0 | 188.4 | Pass | 44.487 | 182.3 | 300.0 | 117.7 | Pass | 41.969 | 0.0182 | 0.2550 | 0.2368 | Pass | 44.475 | 0.0365 | 0.2644 | 0.2279 | Pass | 61.952 | 0.0000 | 0.0083 | 0.0083 | Pass | N/A | N/A | N/A | N/A | N/A | N/A | Pass | N/A | Pass | N/A | Pass | N/A | Pass | 30.2 | Pass | N/A | N/A | N/A | N/A | N/A | N/A | N/A | N/A | N/A | N/A | N/A | N/A | N/A | N/A | N/A | N/A
DDR_BA0 | Pass | Write rank(1,1) | U1.M1 | U2.N2 | 137.7 | 300.0 | 162.3 | Pass | 47.209 | 193.9 | 300.0 | 106.1 | Pass | 7.194 | 0.0370 | 0.2550 | 0.2180 | Pass | 73.353 | 0.0637 | 0.2644 | 0.2007 | Pass | 27.091 | 0.0000 | 0.0083 | 0.0083 | Pass | N/A | N/A | N/A | N/A | N/A | N/A | Pass | N/A | Pass | N/A | Pass | N/A | Pass | 32.6 | Pass | N/A | N/A | N/A | N/A | N/A | N/A | N/A | N/A | N/A | N/A | N/A | N/A | N/A | N/A | N/A | N/A
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

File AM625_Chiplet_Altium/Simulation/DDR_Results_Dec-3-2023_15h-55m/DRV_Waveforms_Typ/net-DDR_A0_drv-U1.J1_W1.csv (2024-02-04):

.HEADER
..NAMES
Time | V U1.J1
.DATA
0.0e+00 | 0.0027
2.33e-11 | 0.0027
4.65e-11 | 0.0027
6.98e-11 | 0.0027
9.31e-11 | 0.0027
1.163e-10 | 0.0027
1.396e-10 | 0.0027
1.629e-10 | 0.0059
1.861e-10 | 0.0321
2.094e-10 | 0.1137
2.327e-10 | 0.2741
2.559e-10 | 0.4022
2.792e-10 | 0.5059
3.025e-10 | 0.5803
3.257e-10 | 0.6256
3.490e-10 | 0.6492
3.723e-10 | 0.6591
3.955e-10 | 0.6619
4.188e-10 | 0.6610
4.421e-10 | 0.6559
4.653e-10 | 0.6508
4.886e-10 | 0.6464
5.119e-10 | 0.6434
5.351e-10 | 0.6420
5.584e-10 | 0.6432
5.817e-10 | 0.6466
6.049e-10 | 0.6517
6.282e-10 | 0.6583
6.515e-10 | 0.6665
6.747e-10 | 0.6773
6.980e-10 | 0.6915
7.213e-10 | 0.7137
7.445e-10 | 0.7501
7.678e-10 | 0.8006
7.911e-10 | 0.8615
8.143e-10 | 0.9292
8.376e-10 | 0.9988
8.609e-10 | 1.0634
8.841e-10 | 1.1183
9.074e-10 | 1.1622
9.307e-10 | 1.1961
9.539e-10 | 1.2211
9.772e-10 | 1.2375
1.0005e-09 | 1.2464
1.0237e-09 | 1.2497
1.0470e-09 | 1.2492
1.0703e-09 | 1.2460
1.0935e-09 | 1.2414
1.1168e-09 | 1.2365
1.1401e-09 | 1.2326
1.1633e-09 | 1.2307
1.1866e-09 | 1.2314
1.2099e-09 | 1.2341
1.2332e-09 | 1.2360
1.2564e-09 | 1.2340
1.2797e-09 | 1.2268
1.3030e-09 | 1.2139
1.3262e-09 | 1.1964
1.3495e-09 | 1.1768
1.3728e-09 | 1.1591
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

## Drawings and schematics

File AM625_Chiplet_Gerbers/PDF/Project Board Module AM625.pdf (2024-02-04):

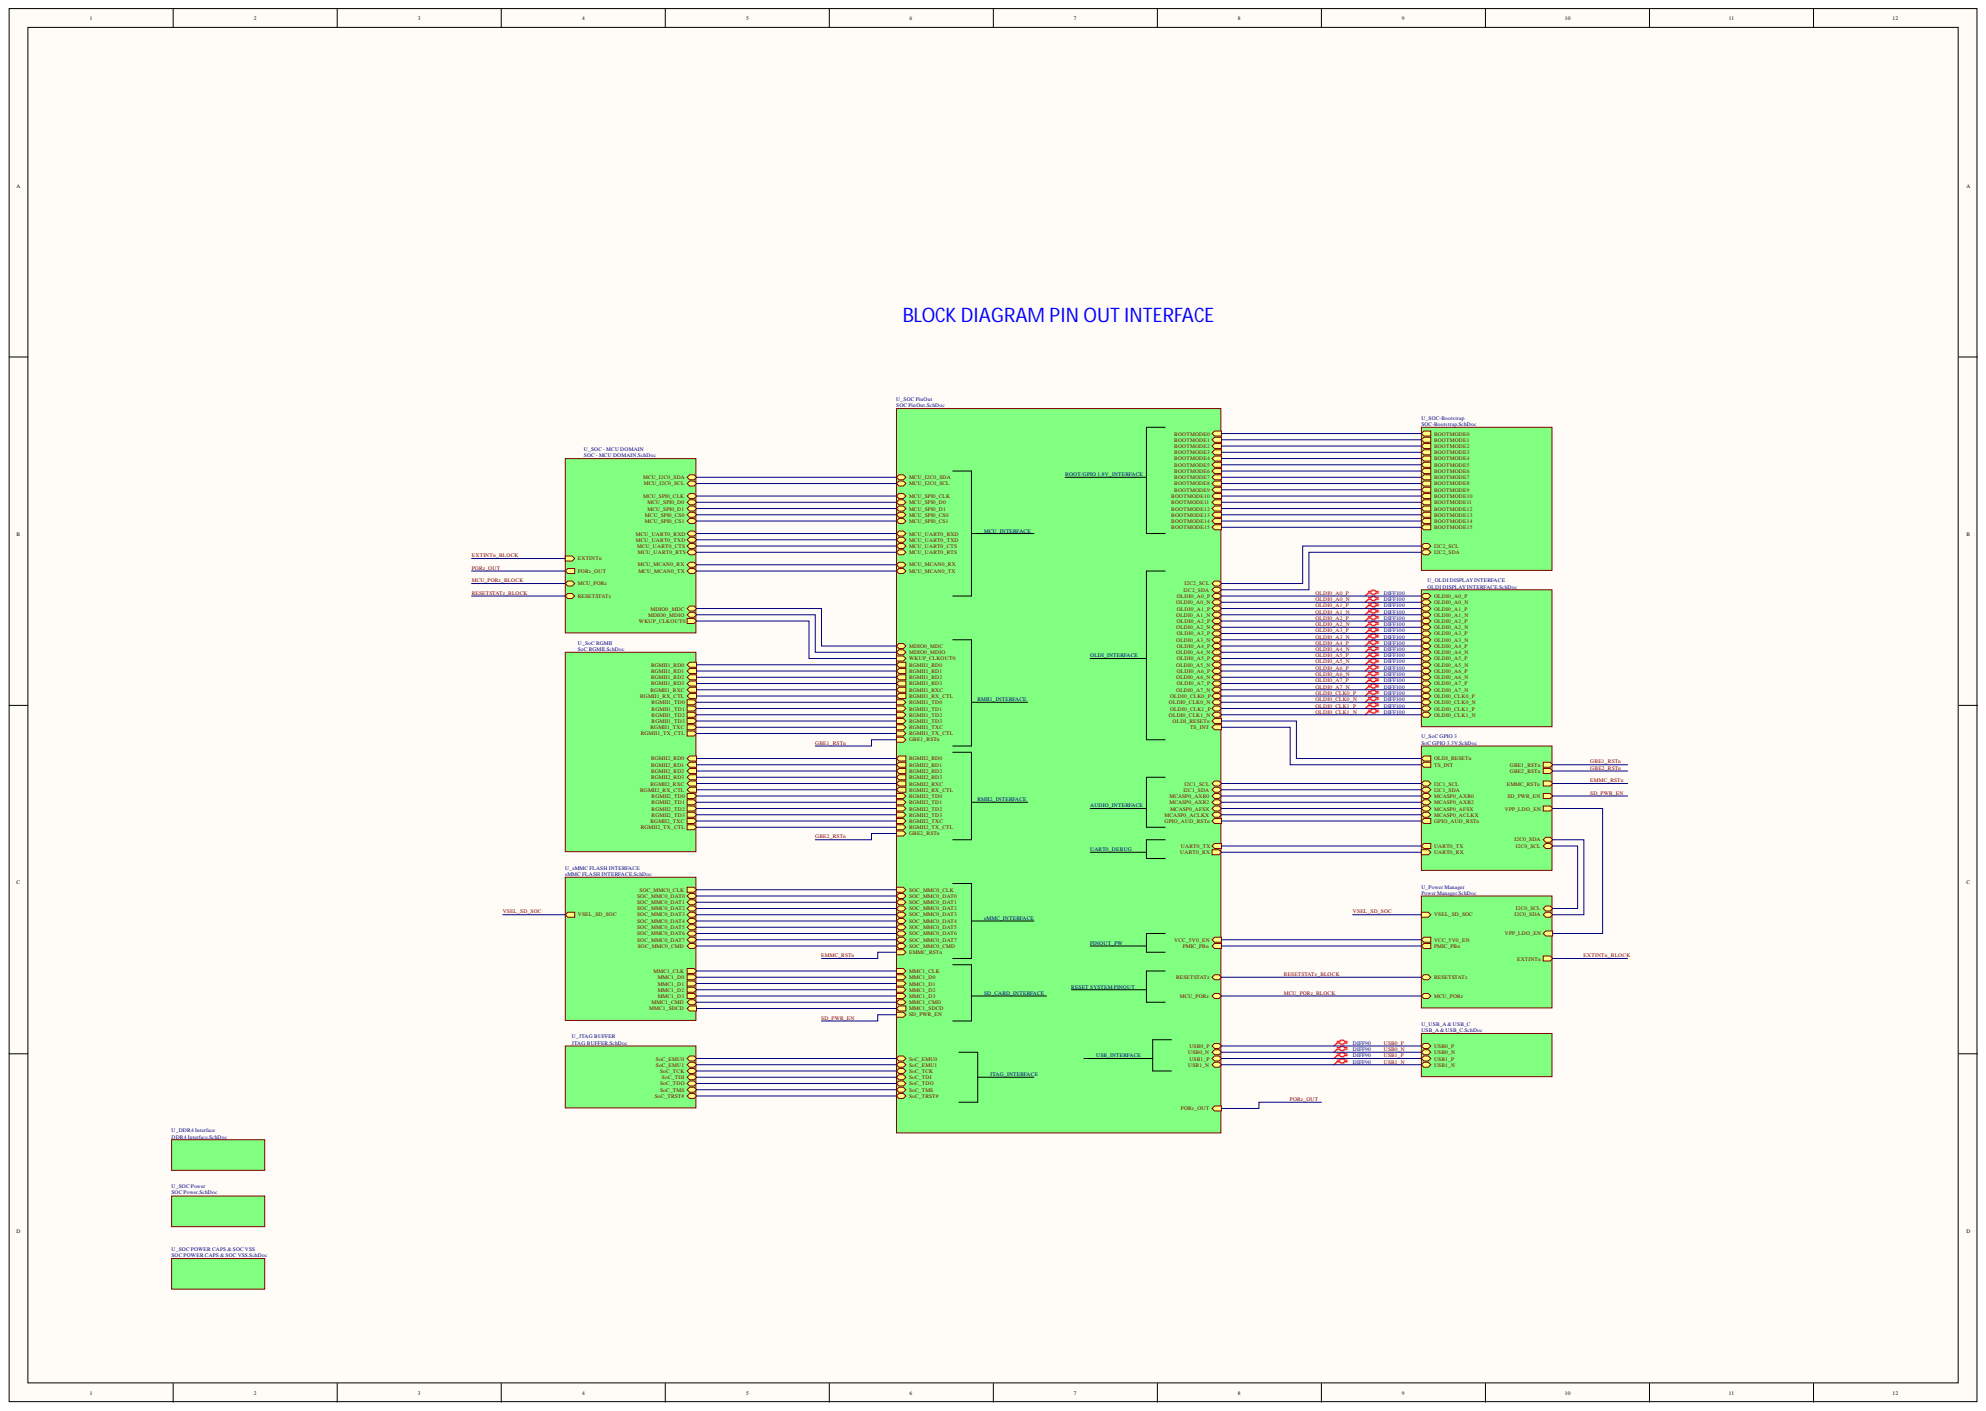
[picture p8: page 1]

BLOCK DIAGRAM PIN OUT INTERFACE

U_SOC - MCU DOMAIN
SOC - MCU DOMAIN.SchDoc

U_OLDI DISPLAY INTERFACE
OLDI DISPLAY INTERFACE.SchDoc

OLDI0_A0_P DIFF100 OLDI0_A0_N DIFF100 | OLDI0_A0_P OLDI0_A0_N OLDI0_A1_P OLDI0_A1_N OLDI0_A2_P OLDI0_A2_N OLDI0_A3_P OLDI0_A3_N OLDI0_A4_P OLDI0_A4_N OLDI0_A5_P OLDI0_A5_N OLDI0_A6_P OLDI0_A6_N OLDI0_A7_P OLDI0_A7_N OLDI0_CLK0_P OLDI0_CLK0_N OLDI0_CLK1_P OLDI0_CLK1_N

U_eMMC FLASH INTERFACE
eMMC FLASH INTERFACE.SchDoc

U_SOC POWER CAPS & SOC VSS
SOC POWER CAPS & SOC VSS.SchDoc

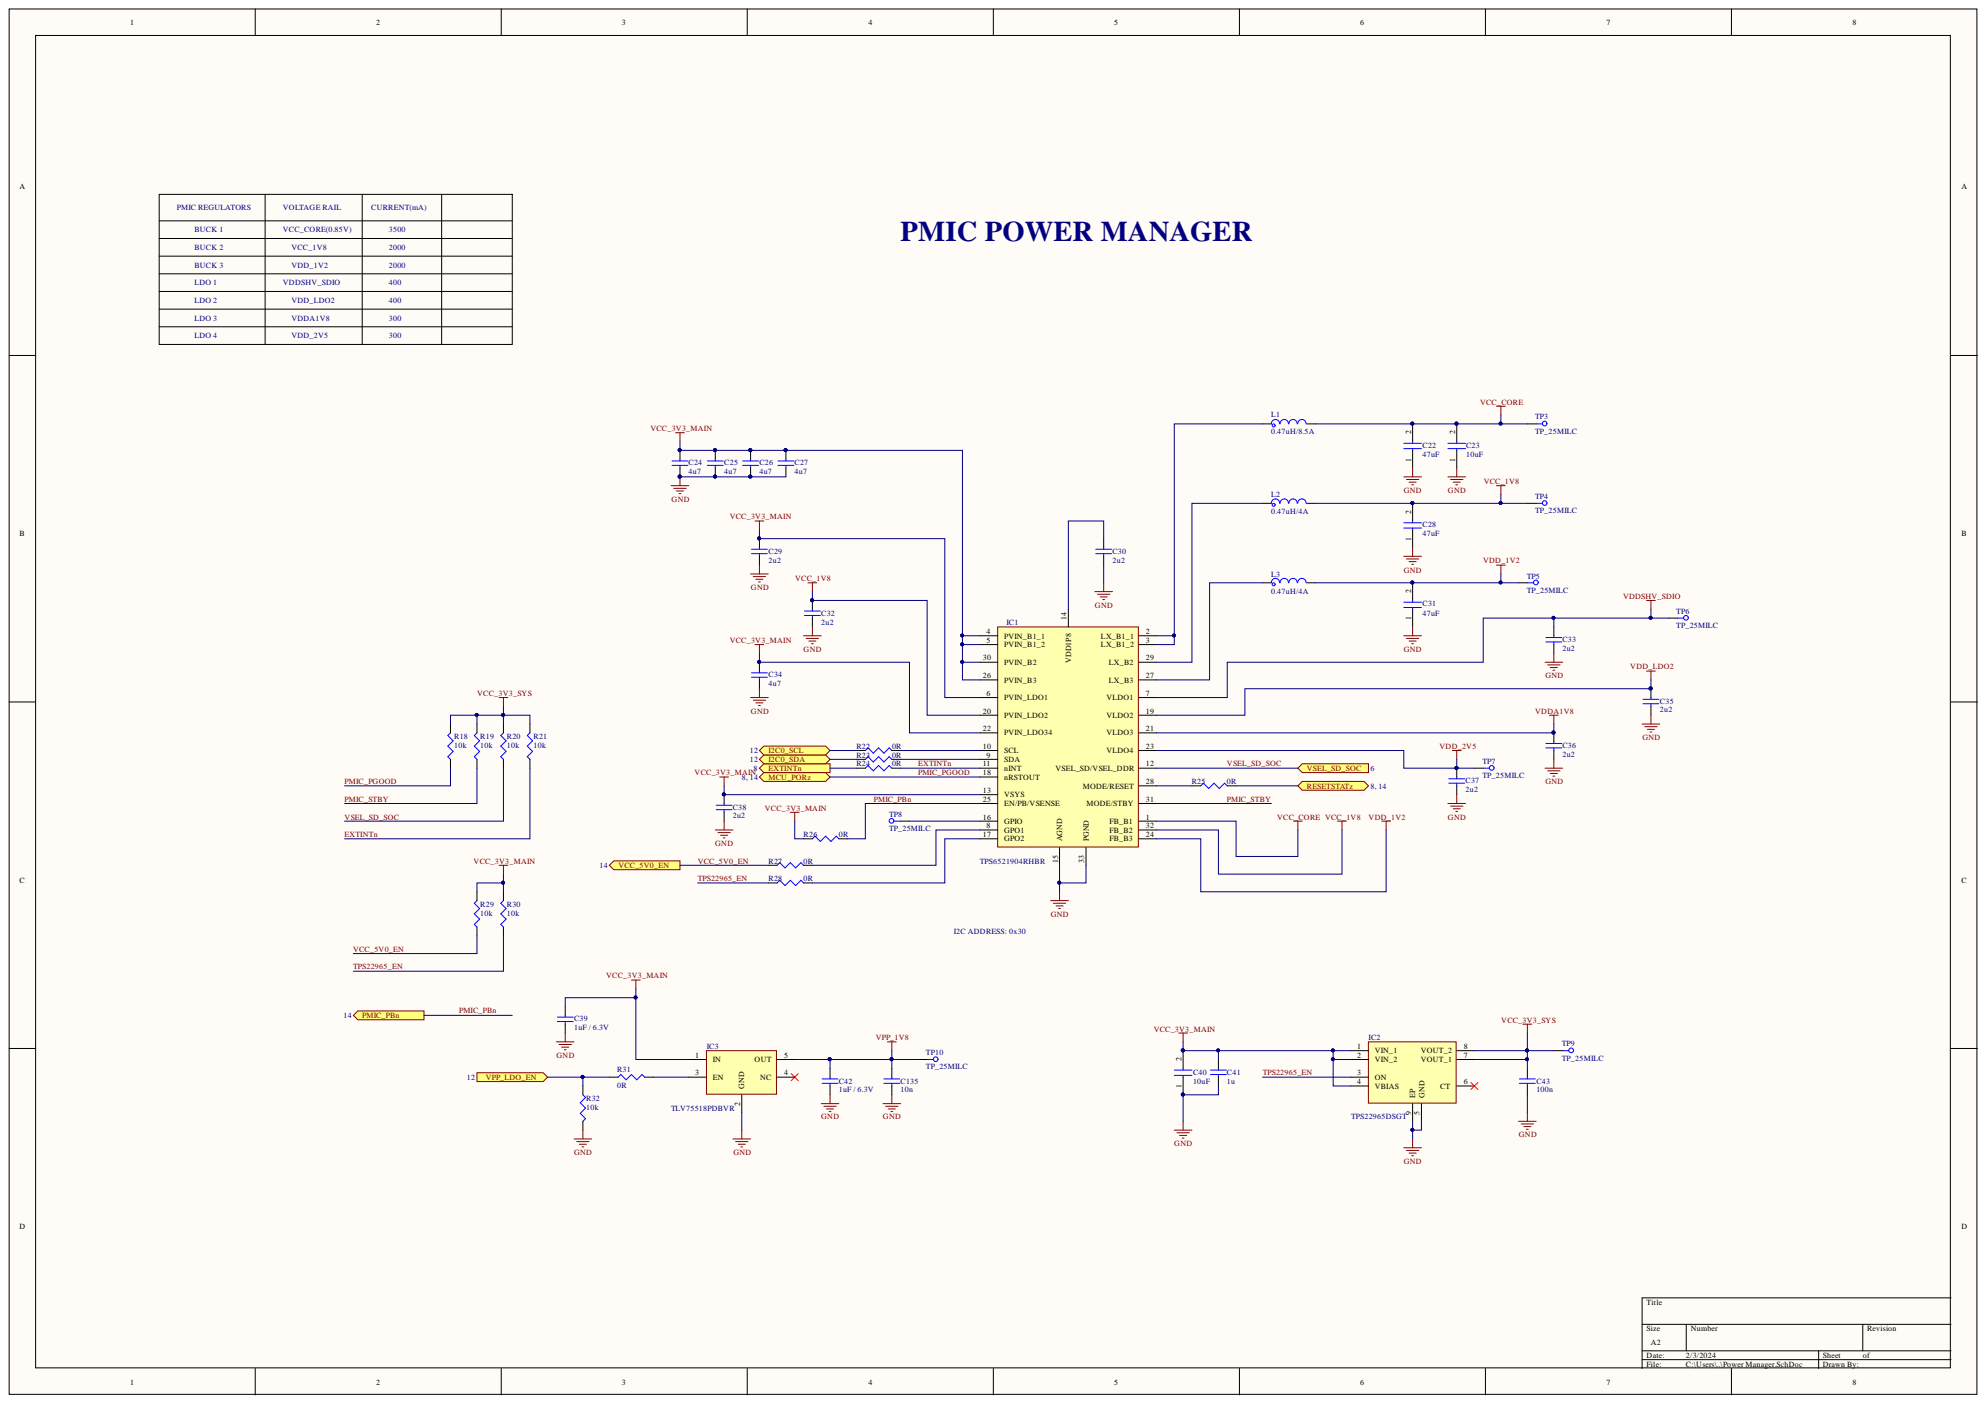
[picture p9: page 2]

PMIC REGULATORS | VOLTAGE RAIL | CURRENT(mA)

BUCK 1 | VCC_CORE(0.85V) | 3500

BUCK 2 | VCC_1V8 | 2000

BUCK 3 | VDD_1V2 | 2000

LDO 1 | VDDSHV_SDIO | 400

LDO 2 | VDD_LDO2 | 400

LDO 3 | VDDA1V8 | 300

LDO 4 | VDD_2V5 | 300

VSEL_SD_SOC

PMIC_PGOOD

ON 3
VBIAS 4

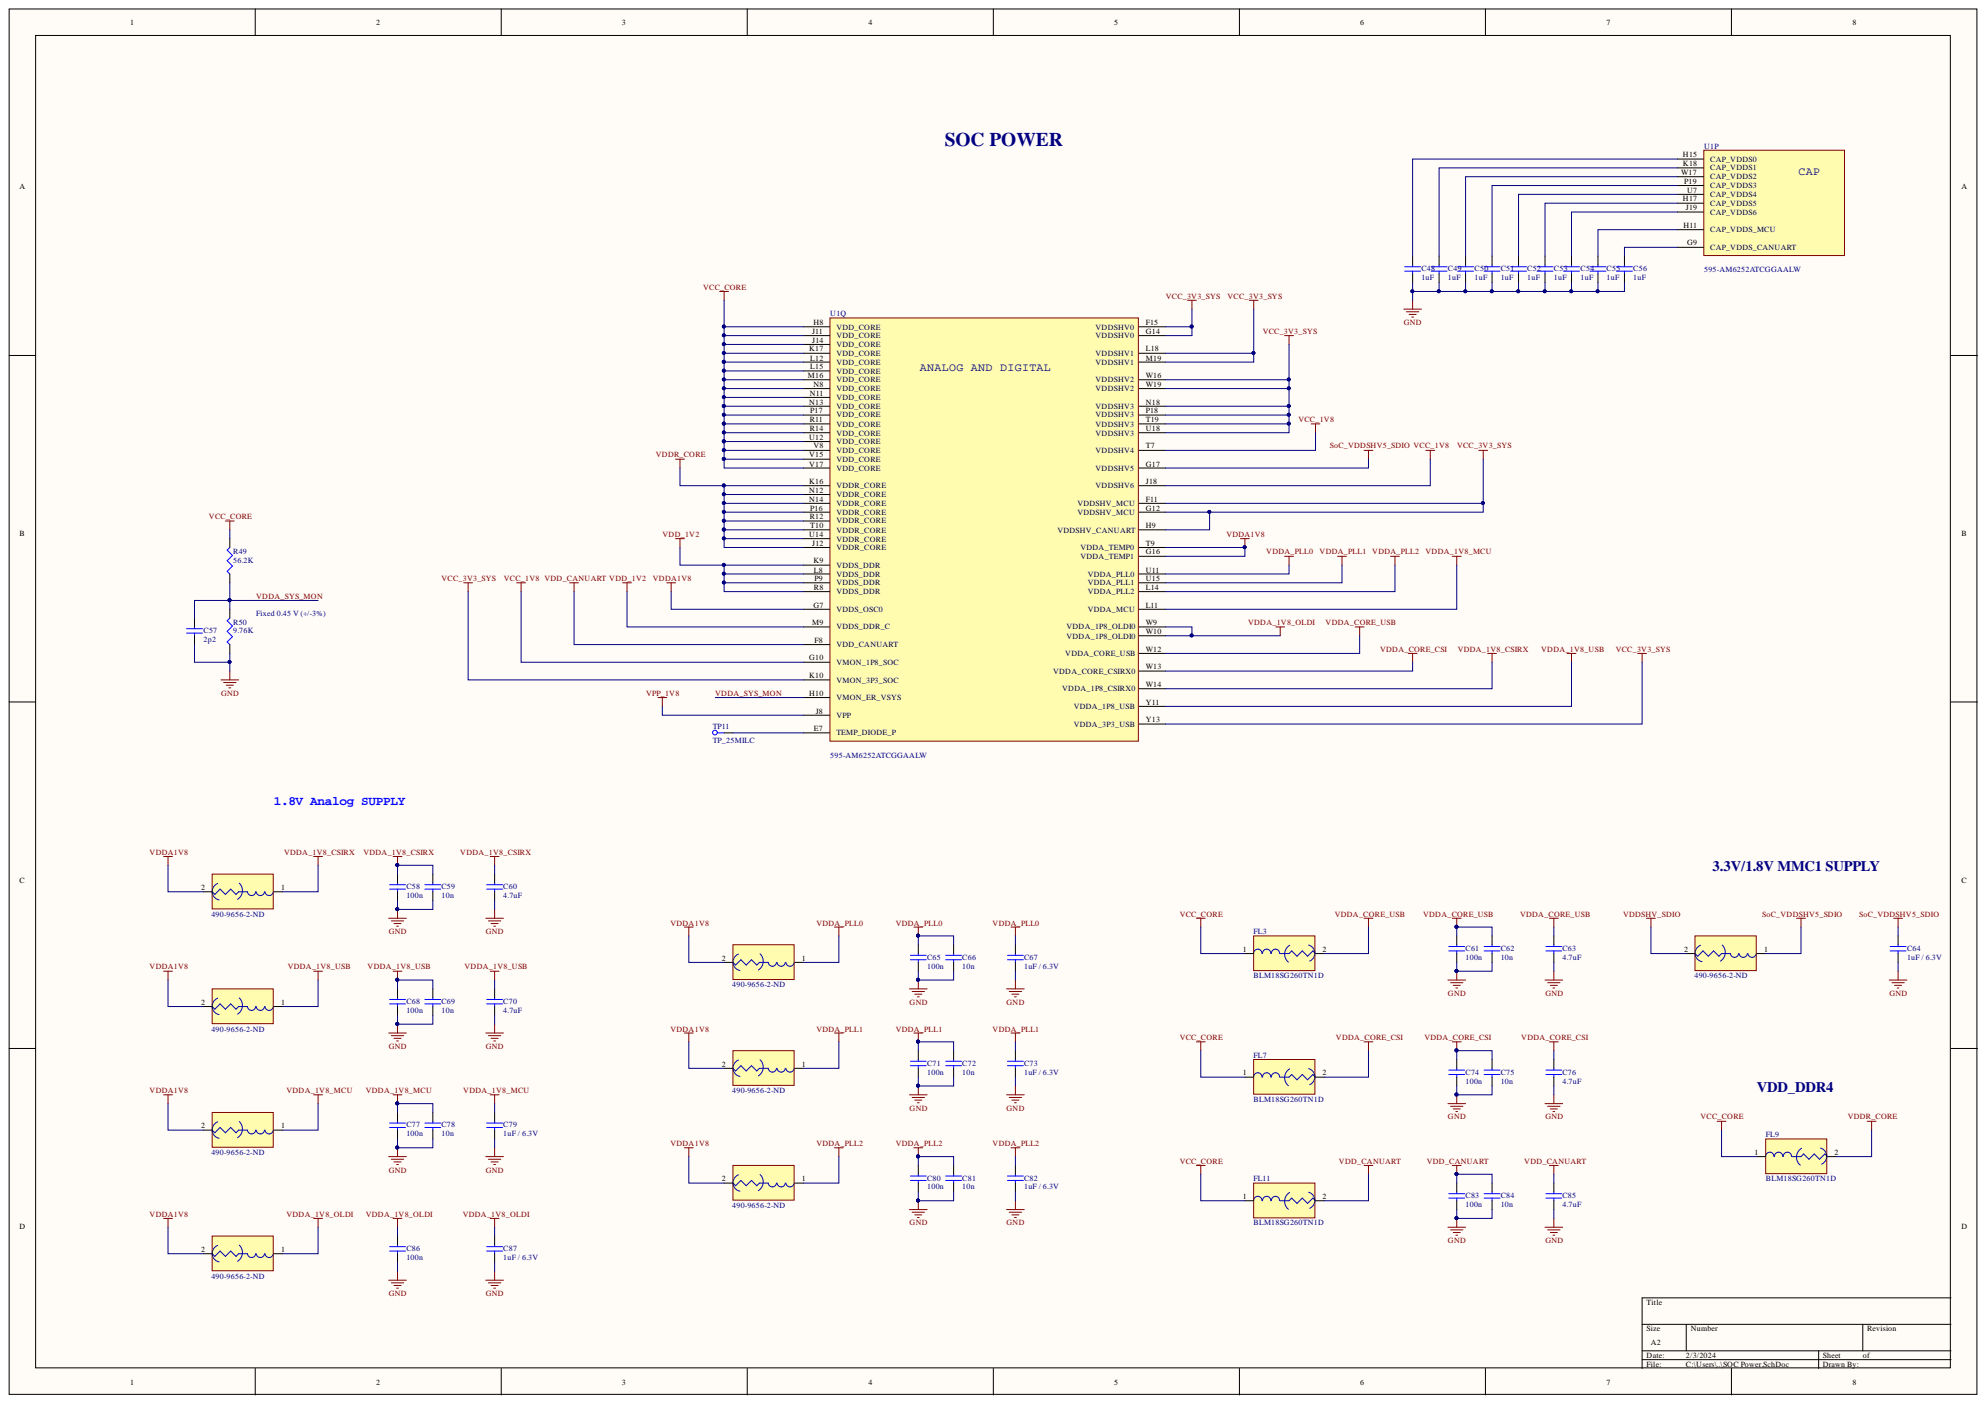
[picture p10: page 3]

K 1 8
W 1 7
P 1 9
U 7
H 1 7

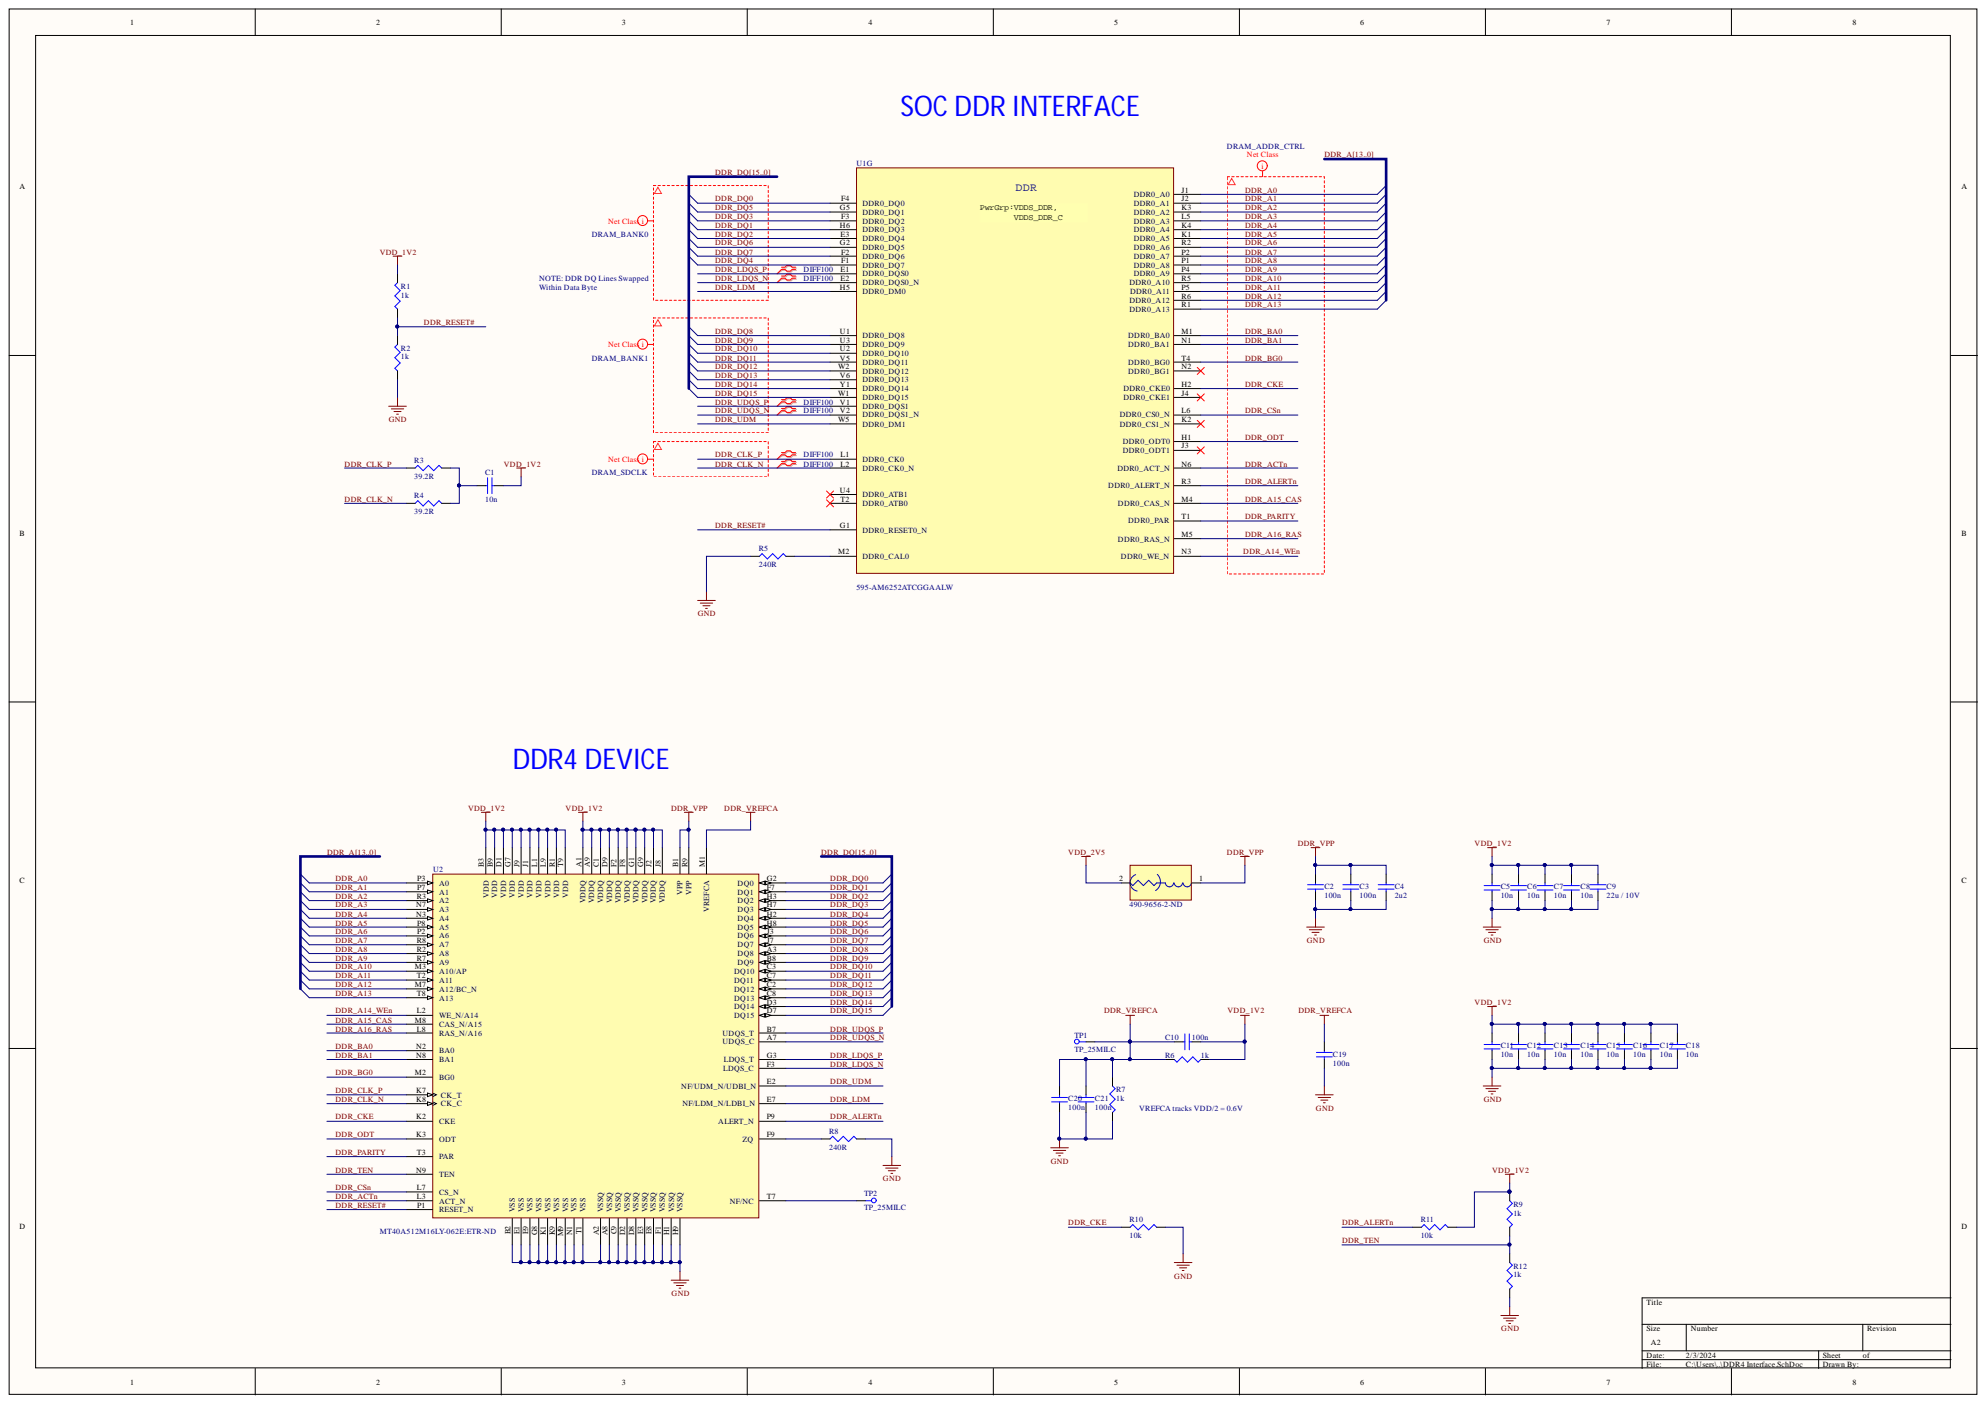
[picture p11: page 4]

NOTE: DDR DQ Lines Swapped
Within Data Byte

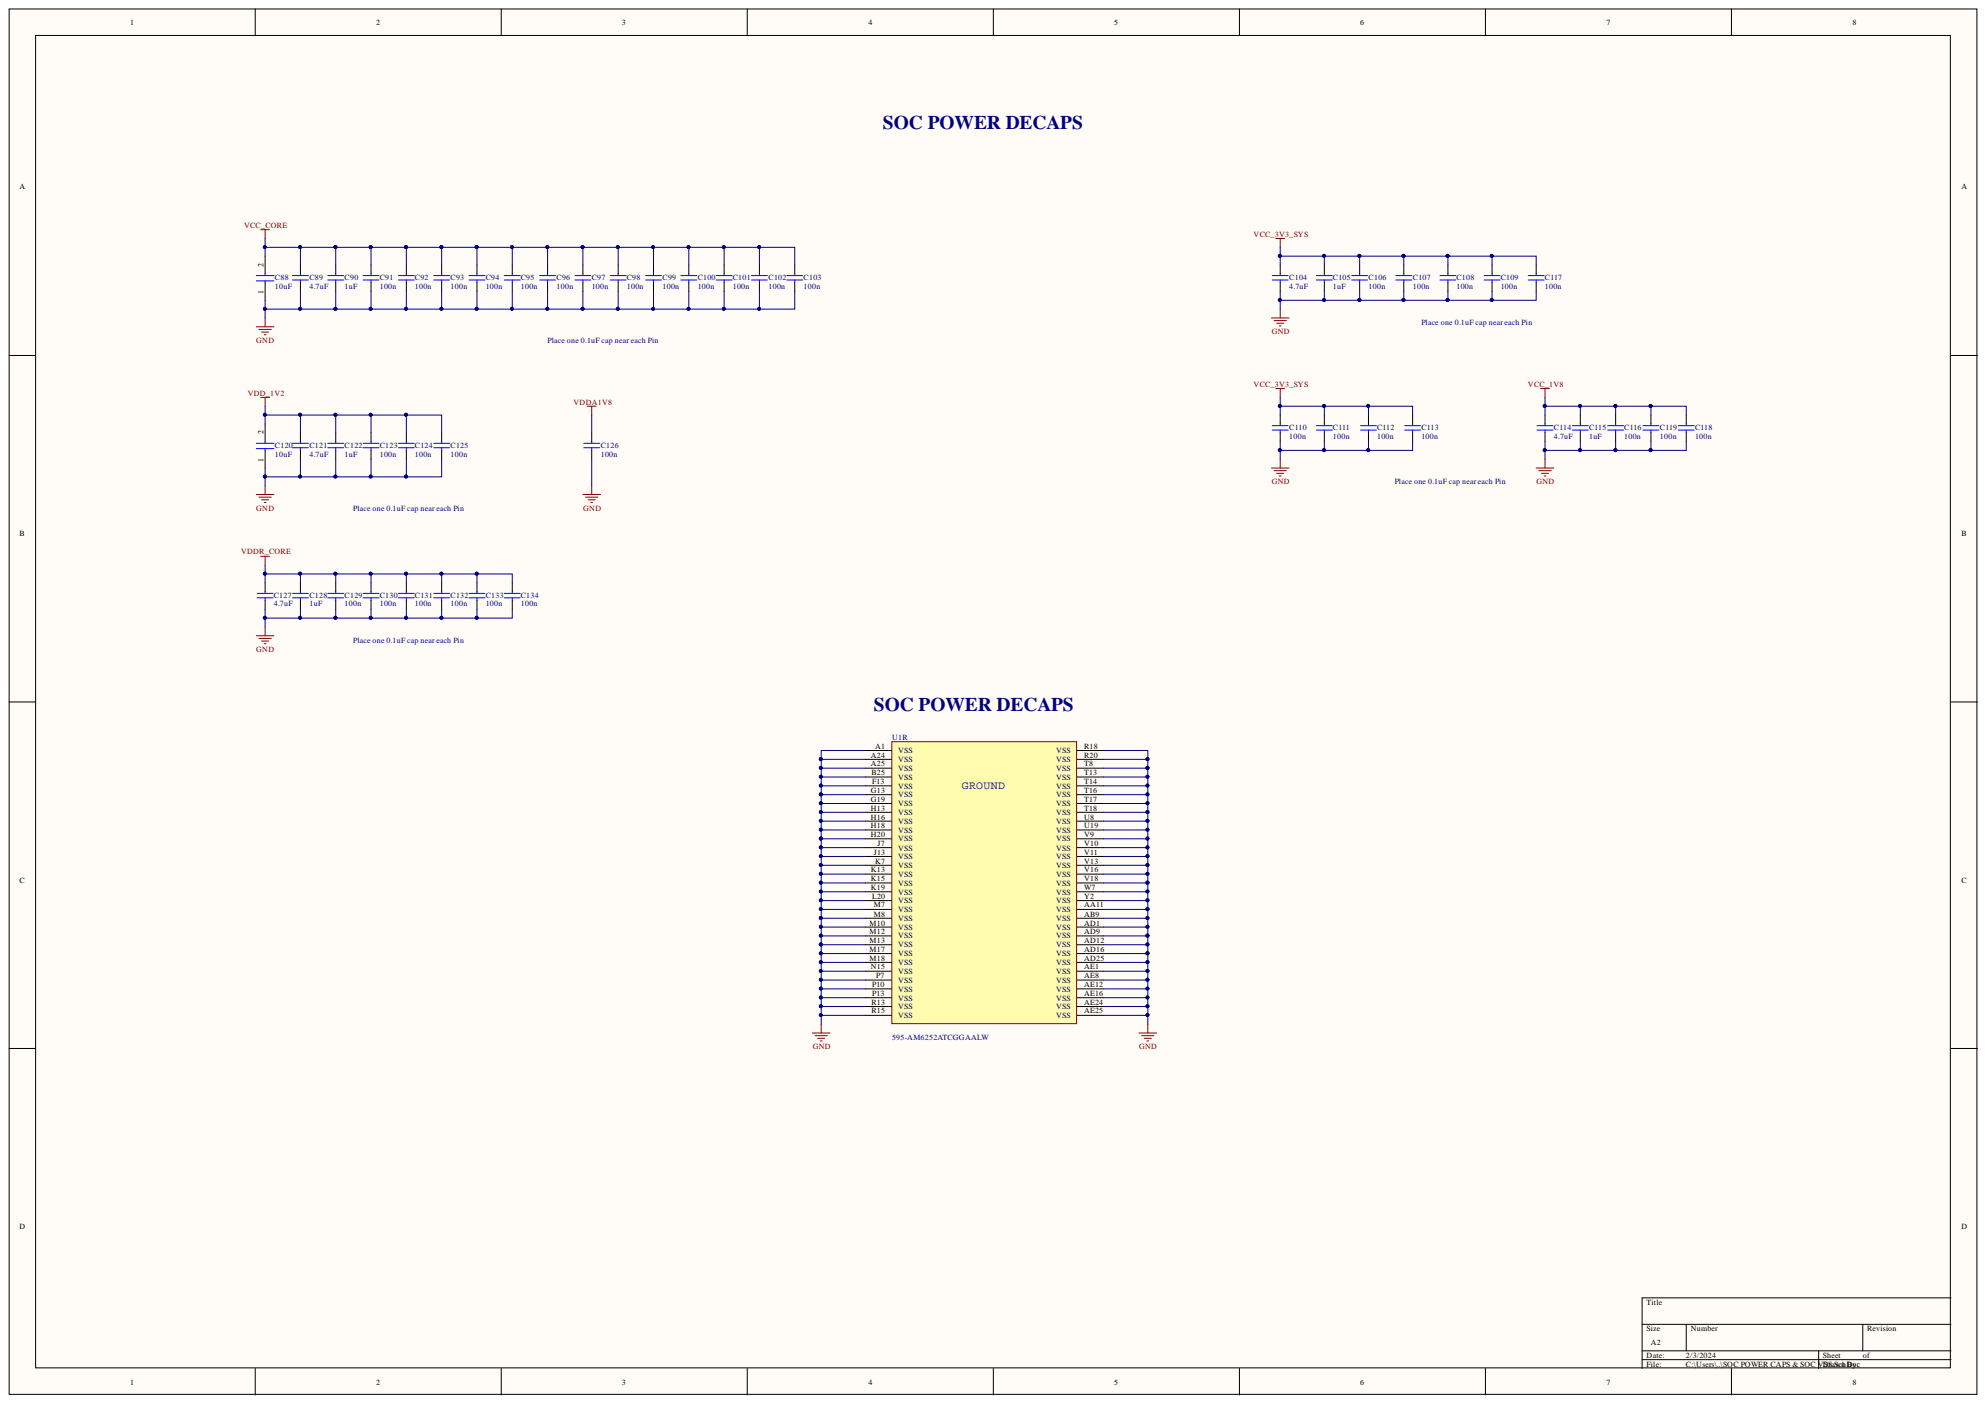
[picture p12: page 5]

Place one 0.1uF cap near each Pin

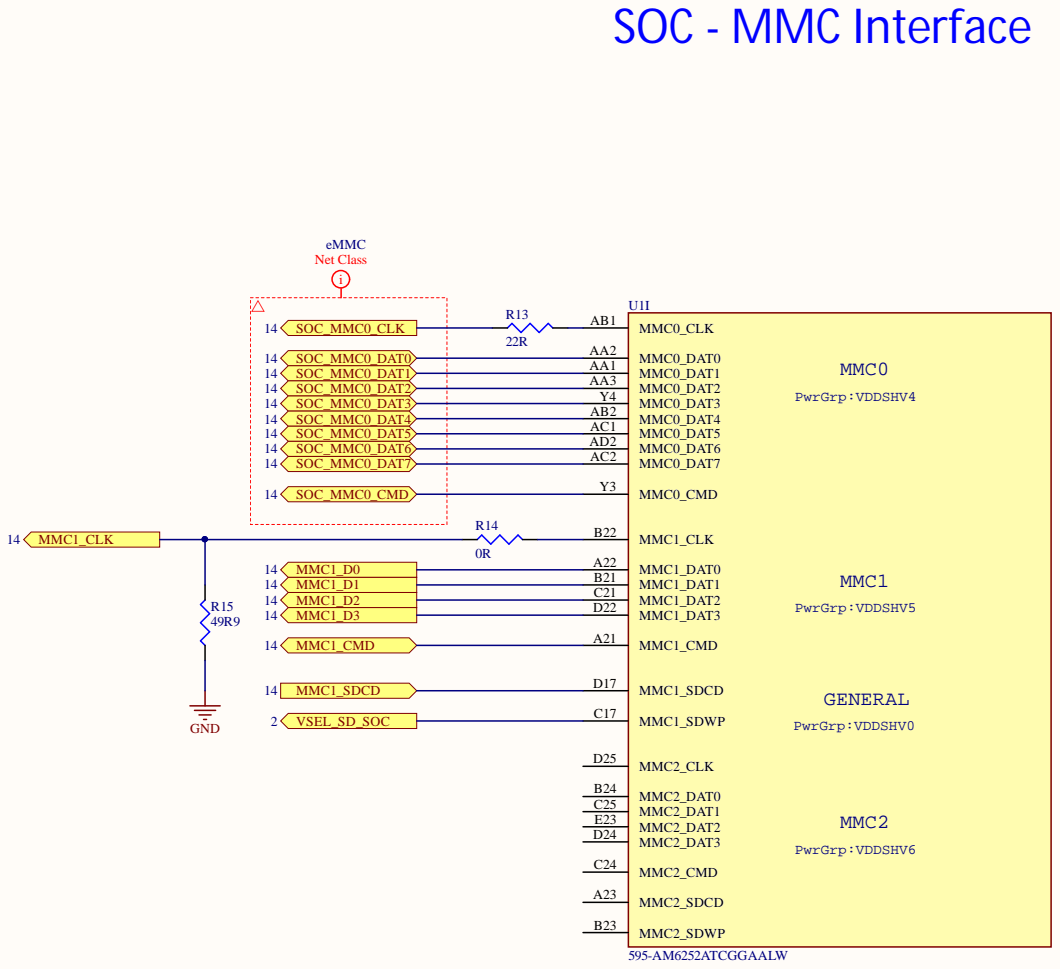
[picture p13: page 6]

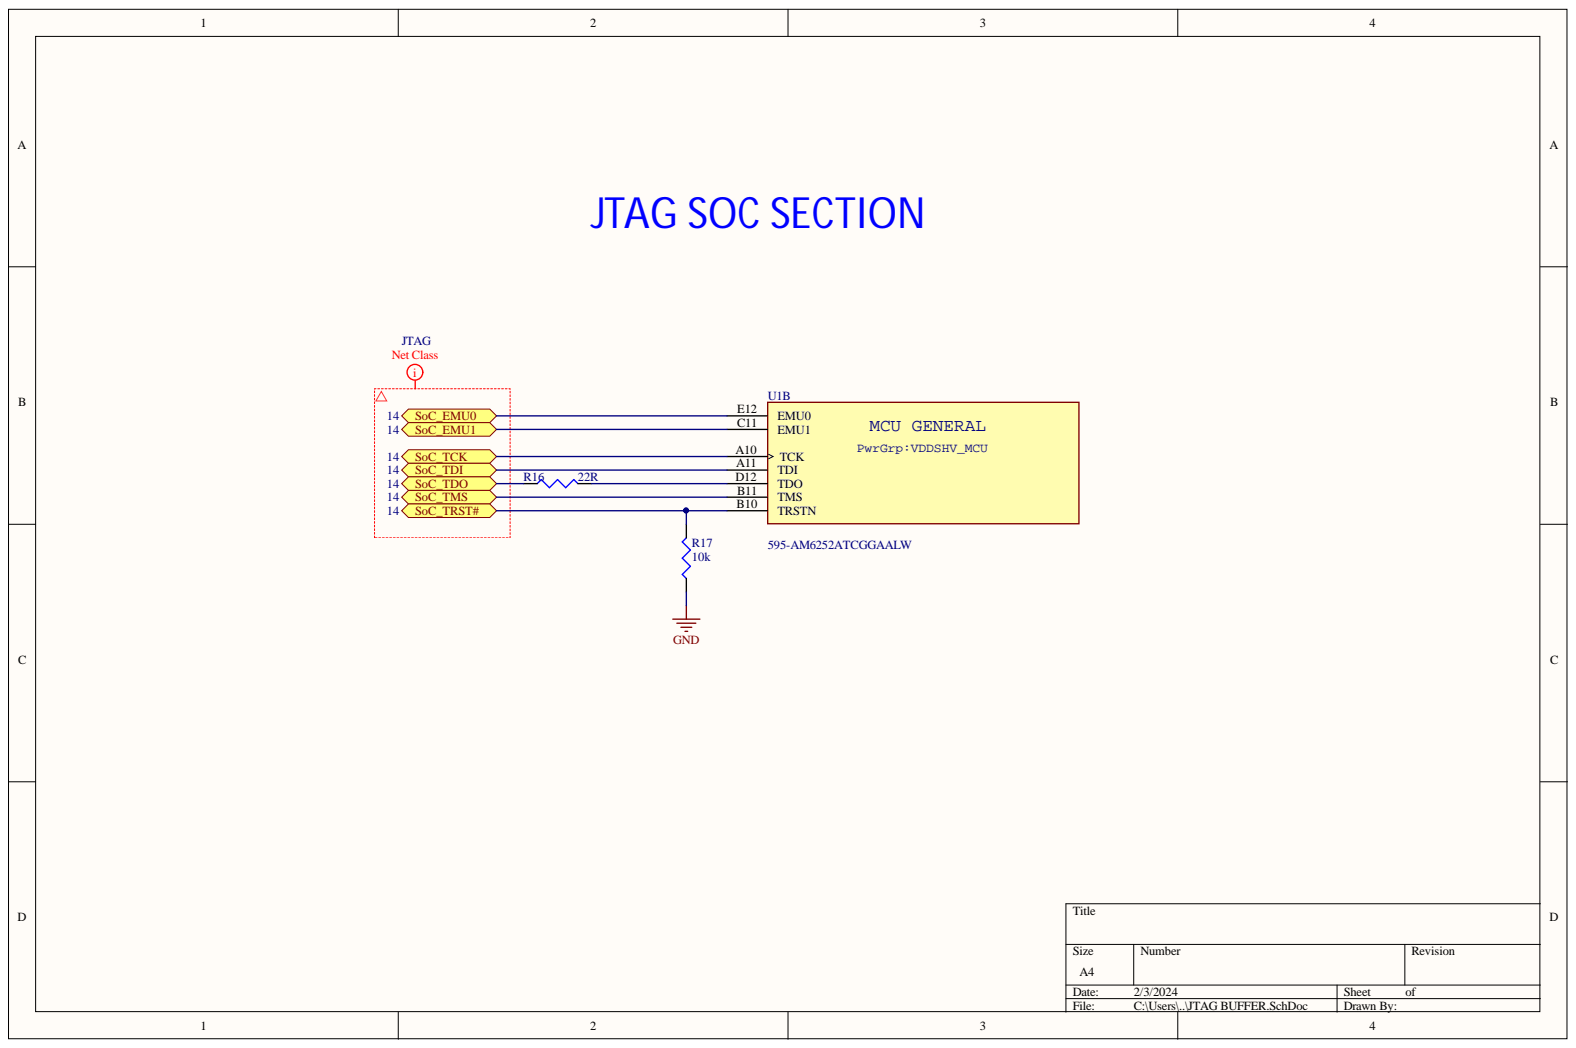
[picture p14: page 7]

Size A4 | Number | Revision

Date: 2/3/2024 | Sheet of
File: C:\Users\..\JTAG BUFFER.SchDoc | Drawn By:

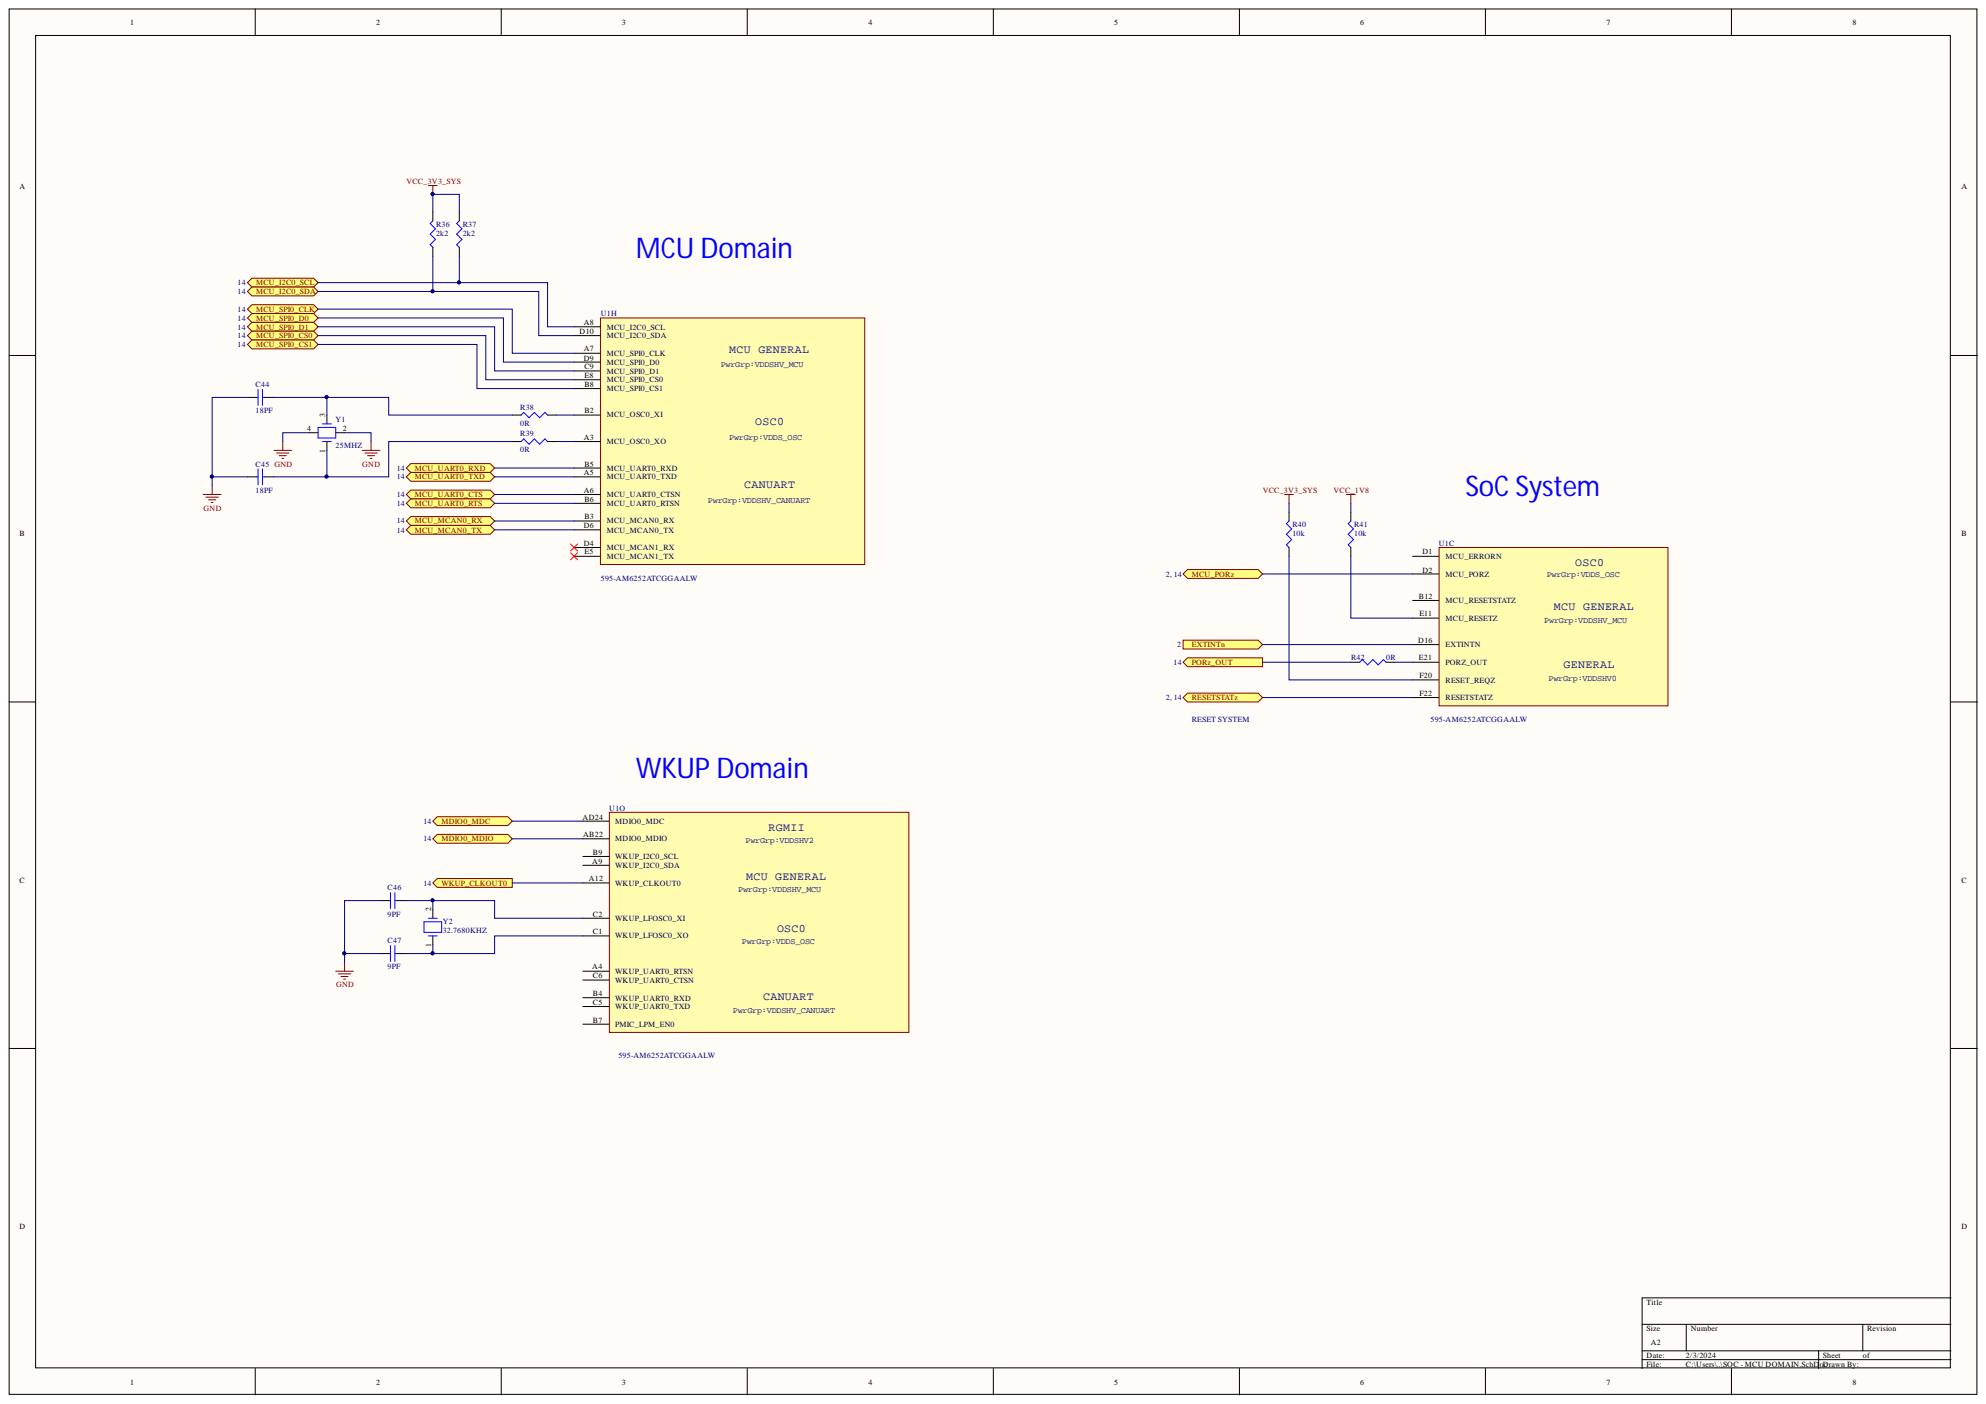
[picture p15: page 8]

MCU_I2C0_SDA D10

MCU_SPI0_CLK A7
MCU_SPI0_D0 D9
MCU_SPI0_D1 C9
MCU_SPI0_CS0 E8
MCU_SPI0_CS1 B8

MCU_OSC0_XI B2 MCU_OSC0_XO A3 MCU_UART0_RXD B5

GND | 25MHZ GND 14 MCU_UART0_RXD

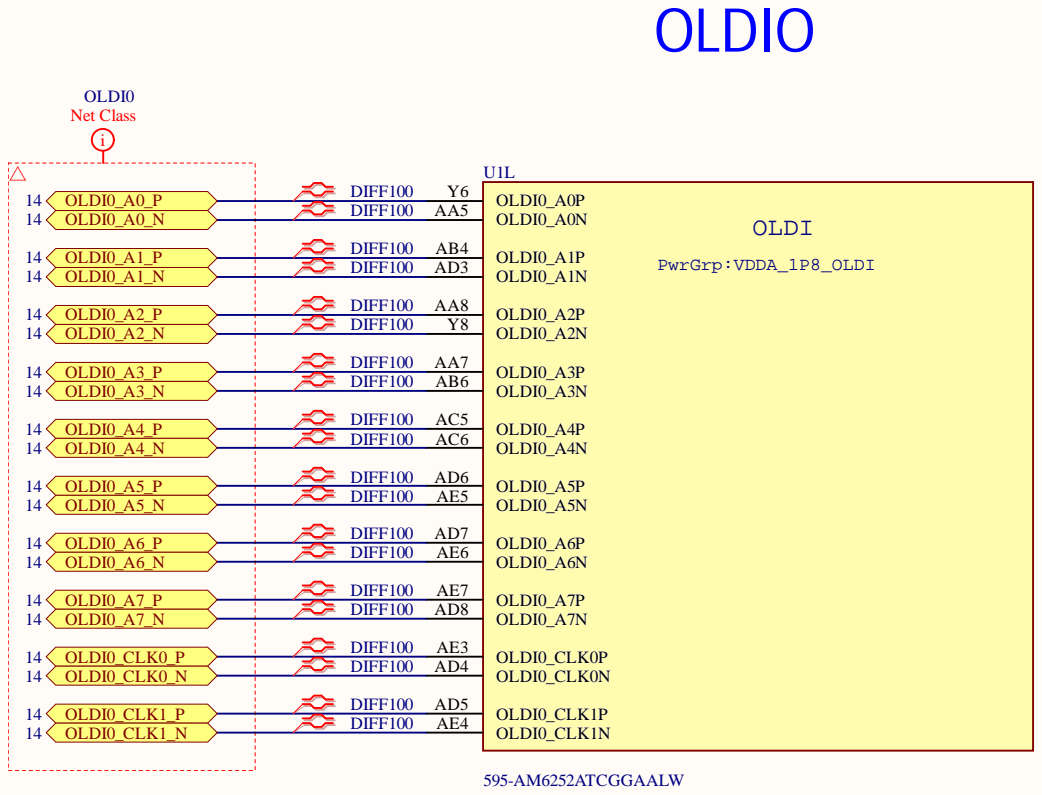
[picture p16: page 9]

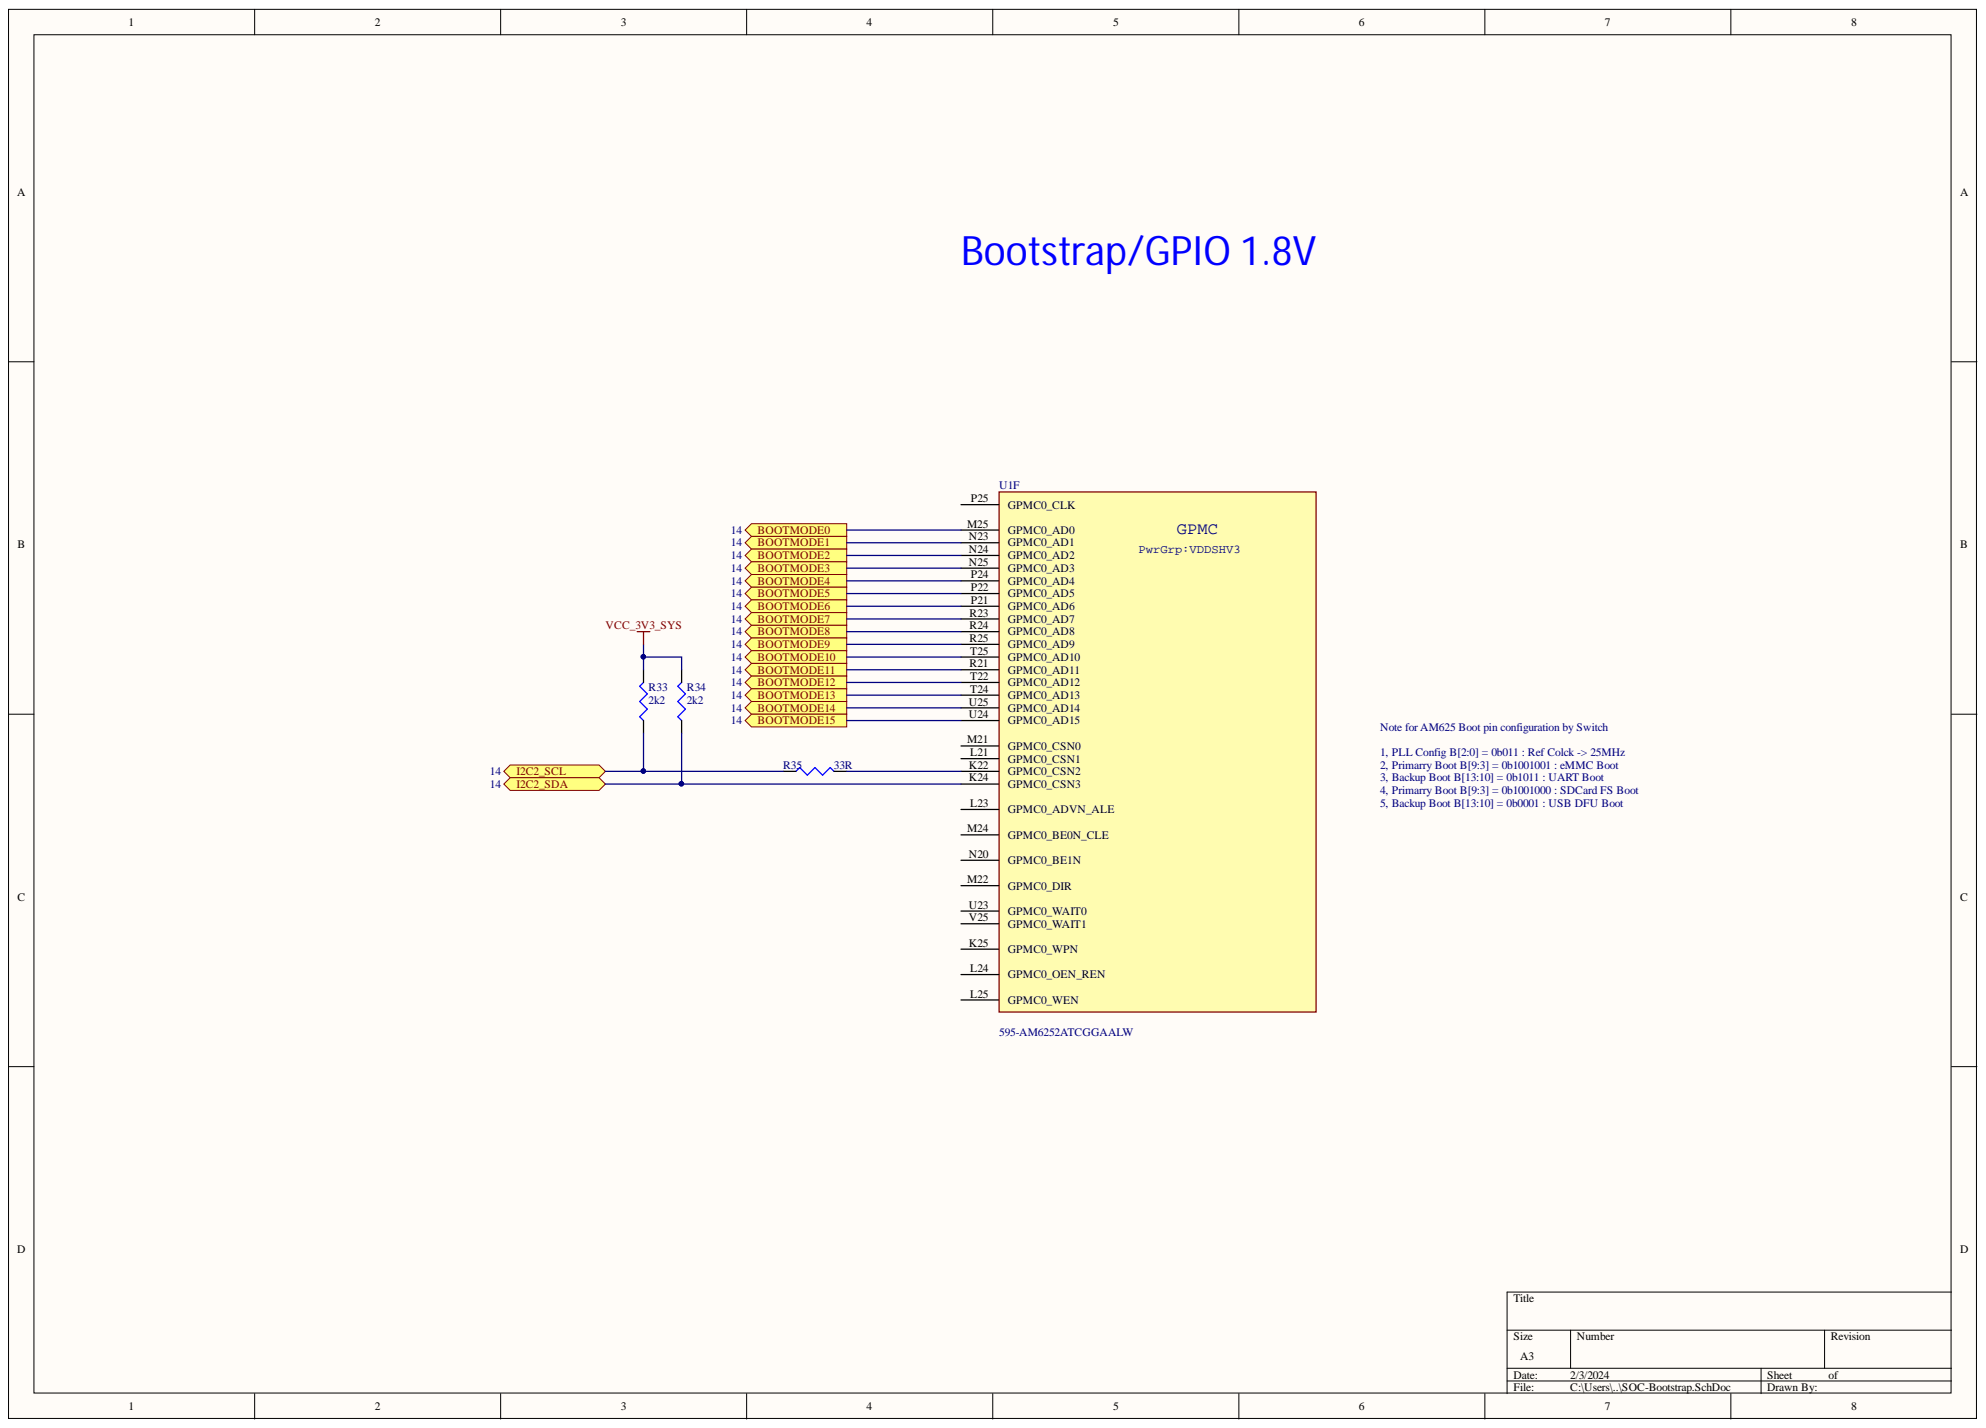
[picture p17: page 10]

Note for AM625 Boot pin configuration by Switch

1, PLL Config B[2:0] = 0b011 : Ref Colck -> 25MHz
2, Primarry Boot B[9:3] = 0b1001001 : eMMC Boot
3, Backup Boot B[13:10] = 0b1011 : UART Boot
4, Primarry Boot B[9:3] = 0b1001000 : SDCard FS Boot
5, Backup Boot B[13:10] = 0b0001 : USB DFU Boot

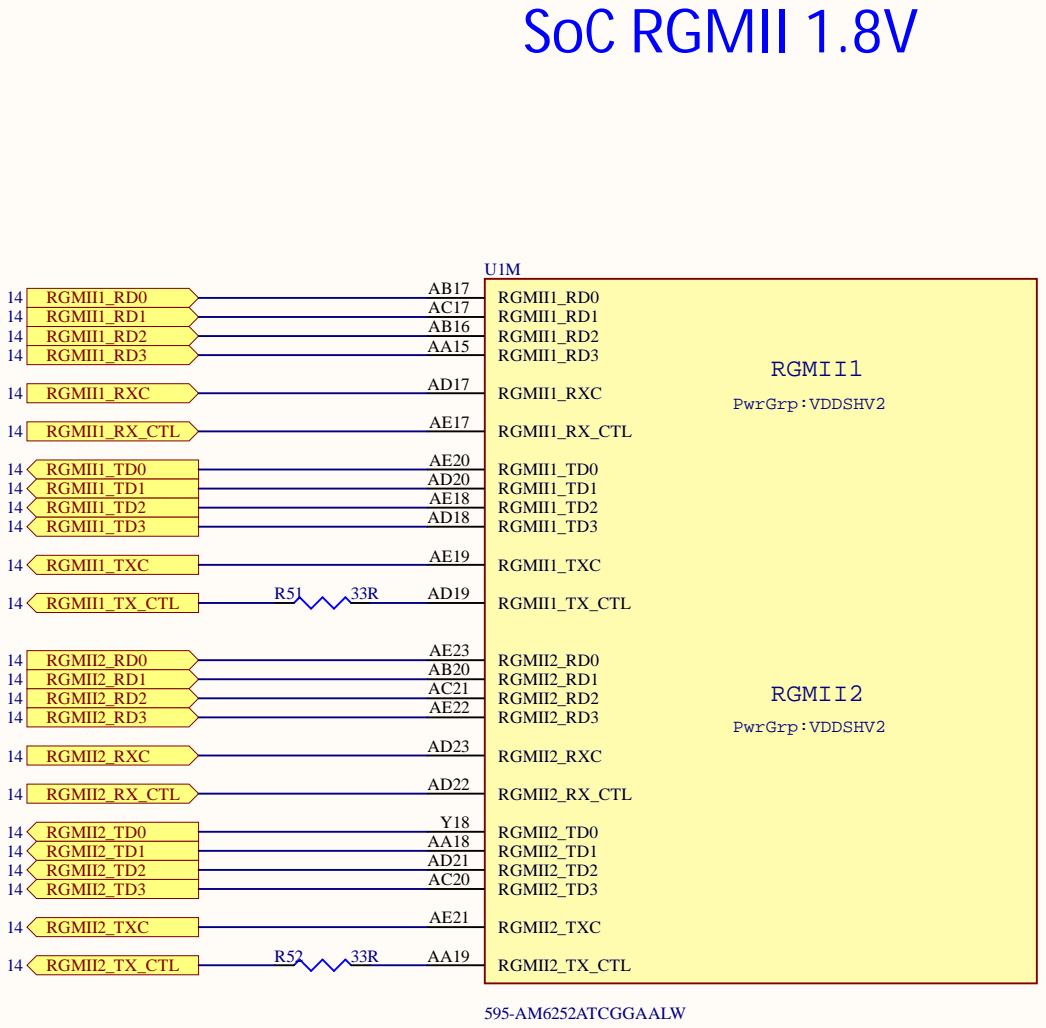
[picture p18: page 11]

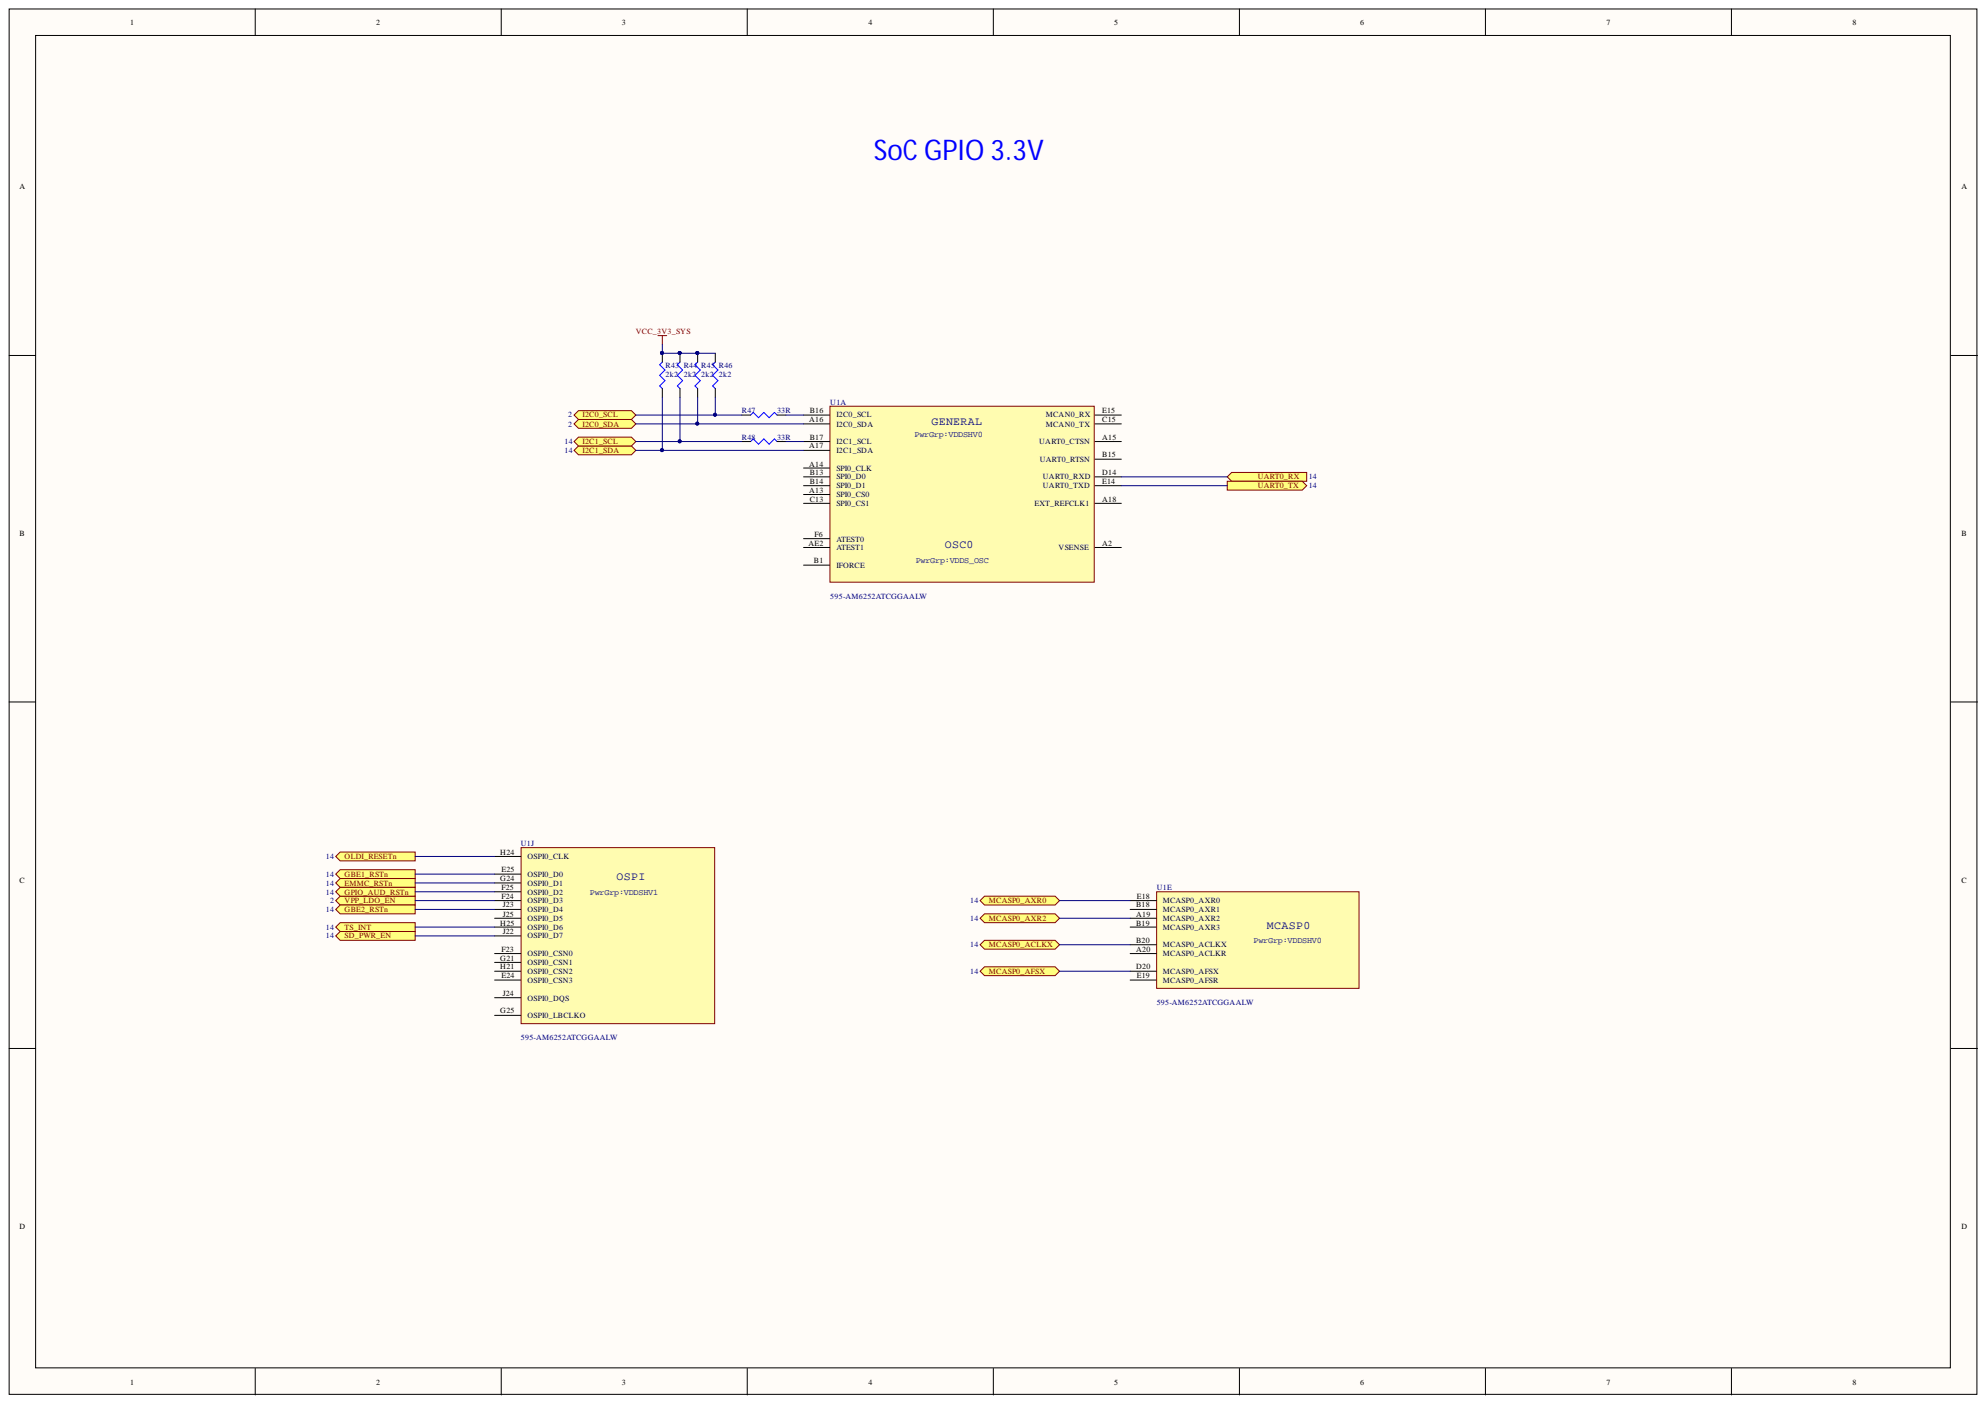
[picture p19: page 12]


USB1_DP AE9 USB1_DM AD10 USB1_RCALIB AC9 USB1_VBUS AB10

R57 10k | USB0_DRVVBUS C20


PIN OUT BOOT/IO

PIN OUT OLDI DISPLAY


# Board Stack Report
